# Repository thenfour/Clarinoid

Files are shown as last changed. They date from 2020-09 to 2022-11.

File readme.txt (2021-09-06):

Clarinoid.

VS Code + platformio for teensy
(GCC)
https://code.visualstudio.com/docs/cpp/config-mingw

....

Info about polyblep oscillators & hard sync:
http://www.martin-finke.de/blog/articles/audio-plugins-018-polyblep-oscillator/
ValimakiPeknenNam-jasa2012.pdf
https://www.cs.cmu.edu/~eli/papers/icmc01-hardsync.pdf

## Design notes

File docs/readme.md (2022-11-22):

# Clarinoid

## Links to other docs

* [Development notes, including how to reduce static memory bloat](development.md)
* [Modulation specification](modulation.md)
* [Notes about oscillator dev](oscillators.md)

## Projects

### Clarinoid2
This is for Clarinoid2, not the original prototype #1. I believe that was arduino only, and had separate LH and RH projects.

### Bassoonoid

### Test Device
I don't think this is actually used, but should be now that the test device is working.

### Bommanoid

## Control / input mapping

So i wrote this a while ago (2020) and forgot how it works, several times. Therefore lets document it a bit? I'll use Bassoonoid as an example.

The point is to go from hardware input to something that can be used deep in code. Buttons can perform functions. Pressure sensors and potentiometers will map float value to float value.

One of the reasons the design is more complex than you might think is because I want to support user-editable control mappings. So mappings are unified in a generic way, theoretically configurable at runtime. This is not possible yet but maybe in the future?

### Base system settings / enum PhysicalControl

```c++
    BaseSystemSettings.hpp / 
    enum class PhysicalControl : uint8_t
    {
        CPBack,
        CPOk,
        Breath,
        Pitch,
        ...
        COUNT,
    }

```

### Control mapper

```c++
    struct BommanoidControlMapper : IInputSource, ITask

    virtual void TaskRun() override
    {
        NoInterrupts _ni;
        mEncoder.Update();

    virtual void InputSource_Init(struct InputDelegator *p) override
    {
        mControlInfo[(size_t)PhysicalControl::Enc] = ControlInfo{"ENC", &mEncoder};
```
### IInputSource

```c++
    struct IInputSource
    {
        virtual void InputSource_Init(struct InputDelegator *) = 0;
        virtual size_t InputSource_GetControlCount() = 0;
        virtual ControlInfo InputSource_GetControl(PhysicalControl index) = 0;
        virtual void InputSource_ShowToast(
            const String &s) = 0; // this is a bit odd but allows the input delegator to show toasts to the GUI.
    };
```

### ControlInfo

### App init

Create default control mappings:

```c++
        mInputDelegator.Init(&mAppSettings, &mControlMapper);

        mAppSettings.mControlMappings[0] =
            ControlMapping::MomentaryMapping(PhysicalControl::LHOk, ControlMapping::Function::MenuOK);
        mAppSettings.mControlMappings[1] =
            ControlMapping::MomentaryMapping(PhysicalControl::LHBack, ControlMapping::Function::MenuBack);
```

### InputDelegator

The `InputDelegator` is a generic class which performs mapped actions. While controlmapper associates hardware controls with control info, input function mappings are in app settings. `InputDelegator` will bring all this together. It looks at control mappings in your settings, and applies the functions / param mappings.

Seems simple, but it means there are a set number of fixed "virtual controls" that real controls map to, or other control destinations. All those virtual controls derive from `FunctionHandler` and must implement `Update` and `GetCurrentValue`.

**Note** that this is not an `ITask`; it is not part of the TaskManager cycle. It's updated from `MusicalStateTask`. Why? Not sure really.

```c++
struct InputDelegator
{
    AppSettings *mpAppSettings = nullptr;
    IInputSource *mpSrc = nullptr; // <-- the app-specific control mapper

    VirtualSwitch mMenuOK;
    VirtualEncoder mMenuScrollA;
    VirtualAxis mBreath;
    SynthPresetAMappableFunction mSynthPresetAFn;
    ///...

    void Init(AppSettings *appSettings, IInputSource *psrc)
    {
        RegisterFunction(ControlMapping::Function::Nop,
                         &mMenuBack); // anything works; it's never called.

        RegisterFunction(ControlMapping::Function::MenuOK, &mMenuOK);
        RegisterFunction(ControlMapping::Function::MenuScrollA, &mMenuScrollA);
        RegisterFunction(ControlMapping::Function::Breath, &mBreath);
        RegisterFunction(ControlMapping::Function::SynthPresetA, &mSynthPresetAFn);
        ///...
    }

    void Update()
    {
        /// for each input mapping, finds the FunctionHandler for it, and calls fn->Update(mapping, controlmapper)
    }
};

```

### FunctionHandler

```c++
    virtual ControlValue FunctionHandler_GetCurrentValue() const = 0;
    virtual void FunctionHandler_Update(const ControlValue &) = 0;
```

## what happens when you press a button, turn an encoder, or apply breath pressure?

1. `BommanoidControlMapper::TaskRun()` updates the internal value of the control. The internal value is not unified; it's basically managed by the driver itself. So a simple: `mEncoder.Update();`.
1.

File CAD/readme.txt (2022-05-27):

for teensy footprints & symbols, go to 
https://github.com/XenGi/teensy_library
https://github.com/XenGi/teensy.pretty

why are there Symbols & Symbols2?
because KiCad changed formats so Symbols is old stuff
and Symbols2 is new.

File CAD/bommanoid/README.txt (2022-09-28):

korgmicrokey37.FCStd = nothing really
sketch1.FCStd = nothing really
ideal.FCStd = some bell placement ideas (obsolete mostly)
speakercab1.FCStd = proposed prod design of cab, with actual dimensions
bommanoid00 = sketches of keyboard case design; not for prod
bommanoid01 = fork of clarinoid test device 05; bringing in all bommanoid components.
              schematic, pcb sketches, and footprints added. not everything 100% double-checked.
              beginning to build pcbs out and do final checks, lets fork before i
              ruin my sketches.
bommanoid02 = continuing design & first attempts at routing
bommanoid03 = continuing routing; it's basically done before panelization & jlcpcb BOM
bommanoid04 = very close, including peripheral breakouts. but still bottom assembly issues.
bommanoid05 = RC1. fx loop, suspended castellated subboard for bottom assembly, part selection
              panelization and ERC / DRC are clean (well there are 99 expected errors due to silkscreen & castellated holes bugs)
              separating into separate orders for jlcpcb.

speakercab2.FCStd = some changes to design:
  - 10"
  - downfacing with no baffle (weight!)

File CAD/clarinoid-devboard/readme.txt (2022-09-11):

00 - 20220612 first work of a clarinoid3 test board. maybe biting off more than i can chew though.
01 - 20220612 let's break up that board into multiple sections
    20220618 after some work, this thing is pretty much the MEGA tester with tons of stuff.
              while that's nice work and nice thought, i think it's too risky for 1st try.
              let's simplify then come back to this.
02 - 20220618 - let's simplify back?
     eh, problem is i actually want to test all that stuff in 1 go. let's just make sub-boards.
03 - 20220618 copied from 01. let's just separate certain modules into sub-modules
04 - LED drivers are actually a nightmare and they're not really essential to this project. forget about them.
     need to separate:
     x dac (5)
     - midi
     - would be nice to have a way to switch between battery  or usb power

     20220620: 04 is being produced by jlcpcb

     THIS IS REV 1

05 - now using teensy 4.1 with pins. ready for assembly.
     and even more modular design

     this was rejected; added 05-asm and 05-noasm to separate assembly versus non-assembly boards in hopes
     of cost savings and build simplification.

06 - that still wasn't enough; need to break yet into <=6 designs per board.
     this is exactly the same design as 05, but broken into more separate projects.
     produced by jlcpcb.

     THIS IS REV 2

07 - the battery charge board of 05/06 was faulty somehow. i don't understand why and 2 fried.
     so here a variation with:
     - EH pad as it was on 04
     - inductor correct part #
     - 0.5mm traces
     - output capacitors
     - component sizes matching that of MH-CD42

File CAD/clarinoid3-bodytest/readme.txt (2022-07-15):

fork of devboard-04, combined with body design sketches from \CAD\clarinoid3-devboardfork\00
for proto & testing of physical:
- physical clearance
- ergonomics
- strength of body

- castellated holes
- volume placement & sub-board
- panelization of sub-boards
- inter-board headers
- front & back assembly
- various cap touch slider patterns

00 = initial; actually made a lot of progress already. LH pretty much done.
01 = let's work on RH and try to get this thing produced.
     HM making a lot of progress, main subboard for example.
     but if i want ideal ergonomics / interconnect / component placement,
     then i am really running into space problems. i CAN fit everything,
     but placement is going to be compromised.
     i have this idea now to put the DAC and possible more on a sub-board,
     this will put it together as it's more critical for spacing / grounding,
     and it will ensure everything is close to the audio out jack. let's go to 02.
02 = trying adding more to pot subboard
03 = subboards & routings are done. but i'm not satisfied with the interconnect headers;
     i don't like that these are directly exposed on the outside wall;
     let's try SMT pin header footprints.
     i had also considered more sub-boards, maybe again mounted @ 90 degrees like
     the potentiometer. but mechanical stress & complexity concern me.
     in the spirit of experimenting/testing, let's go for SMD pin headers.

04 = micromod is not ideal for our design. benefit does not outweigh the cost regarding
     vibration, complexity, stability, convention.

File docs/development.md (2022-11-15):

# Random development notes

## Crash handling

Teensy's relatively new crash handling mechanism will output the address of failure. To use it,

1. make sure you build with `-g` to output symbols
```
build_flags =
  -I../../src
  -std=c++17
  -Wall
  -g
```

2. with the address, run:

```
"C:\Users\carl\.platformio\packages\toolchain-gccarmnoneeabi\bin\arm-none-eabi-addr2line.exe" -e "C:\root\git\thenfour\Clarinoid\projects\BOMMANOID\.pio\build\teensy41\firmware.elf" 0x117bc
```

## Bloaty & memory use
Teensy will crash mysteriously when running out of memory. Before 1.54, it was pretty hard to get quick insight about mem usage. But now we can see memory.

RAM1 is getting stretched thin much of the time, leaving a couple dozen kb for stack.

Statically-allocated things like lookup tables go there. So Modcurve LUT, scale follower, static variables.

Also CODE gets copied to RAM1 for speed, and this is actually significant, probably because of the amount of templated code we use.

For this it's very useful to use "bloaty". It runs on *nix (ubuntu in my case).

```
git clone https://github.com/google/bloaty.git
npm install cmake
cd bloaty
git submodule update --init --recursive
make -j6
./bloaty bloaty
```

## C++17

  * https://forum.pjrc.com/threads/58695-c-17
  * https://forum.pjrc.com/threads/60944-C-STL-on-the-Teensy-4-0-not-possible

Unfortunately, even with `-std=c++17`, we only get C++14 support. This is dictated by the platform toolchain, `- toolchain-gccarmnoneeabi @ 1.50401.190816 (5.4.1)`.

It's possible to specify a newer framework in the `platformio.ini`; search for `gccarmnoneeabi` on the registry. https://registry.platformio.org/tools/platformio/toolchain-gccarmnoneeabi

But if you do that, you'll get build & link errors, unable to use many features we require.

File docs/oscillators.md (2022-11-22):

# Oscillator development

## Ring Mod

Ring mod is a fairly "weak" type of modulation, and I have never really found great uses for it. But it's simple to implement.

## Hard Sync

## Band-limiting

## FM

FM is simple to implement, but there are quirks going on to make it behave in a musical way.

### Chained modulation

Phase restart is essential when using FM, otherwise the character would be inconsistent. There would be issues when portamento varies between oscillators too, so it may be that these need to be synchronized between oscillators in the future.

### Feedback

FM Feedback is known for being unstable, but at least it's usable. I found with the naive implementation, it starts to break up in glitchy ways at higher values. Digital-sounding glitches and octave shifting beeps, while the identical algorithm in JSFX or C++ produce expected "stable" waveforms.

See https://github.com/thenfour/Clarinoid/issues/193

Reducing all the way down to a few float ops per sample, and dumping the numeric results of identical code, it's confirmed that it's the result of FM feedback, amplifying and accumulating floating point discrepencies.

* See: `exprcmd.cpp`
* See: `\notes\osc accuracy analysis x86 comparison.xlsx`

For example, modulation between FM oscillators is not a problem. The error doesn't accumulate.

Note: `double` does not seem to affect anything; same glitching occurs.

I could dive deeper but I doubt it would get me closer to a solution. It may be in the implementation of `arm_sin_f32` (although I checked a taylor series version and had the same issues). But I suspect it's in very small differences in multiplication. Multiplying phase by `2*pi` seemed to be a source of error.

I have not found a solution for this, but some mitigations to mind.

* "recording" certain values to capture a single wave cycle. This would eliminate the accumulating errors, and ensure wave cycles sound stable / consistent. Unfortunately there are issues with regards to wave cycles not being exact sample lengths (which would cause detuning at high frequencies). Maybe mitigations can be done, like just calculating 1 fixed long waveform, and interpolating out of it, like a sample player. I'm not sure that would work either though because the feedback sound will depend on the ratio of frequency to samplerate.
* Resetting feedback state every wave cycle. I tried this, setting to either 1 (the value of `sin()` at the start of a cycle) or 0 (the initial state i used in JSFX to get good results); both seem to possibly help, but introduce other glitches and i'm not sure it's actually helping. Prefer simpler solution. Also we're going to suffer the same as above: cycle crossing won't be at even bounds.
* Use fixed-point math. Oscillators don't really benefit from floating-point style behaviors so maybe using fixed 32-bit math would help stabilize things.

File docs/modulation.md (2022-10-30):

# Modulations on Clarinoid

Trying to capture justifications for things here.

Modelled after the modulations I've used in the past. Some systems are not really translatable, like Renoise's meta devices or highly UI-dependent or grid-like types like FM8. But we have enough CPU to probably support whatever we need as long as it's focused and optimized.

The modulation systems that seem to make most sense to inspire from are Massive and Serum. And anyway modulations are not some kind of magic; the system sorta implies the design already. Recent work on 7jam also is largely the basis for this.

Note that modulations are critical for Clarinoid, for a few reasons:

* Mostly monophonic, therefore expression is more important. Modulations are where the richness and expression is.
* Everything revolves around breath, which is a modulation. It better be flexible in order to make diverse sounds.
* Because the filter is sorta blanketing everything, another reason we need other means to spice up the sound and keep it from all sounding the same.

## Algorithm

The fundamental algorithm to start with is

    output = base + modulation

Where `base` is a base value or signal (an oscillator frequency, or amplitude, or LFO rate). `Modulation` is a value or signal to add into the signal.

In practice, all signals are bipolar `[-1,1)`. Even modulation sources like Breath, which doesn't have any concept of negative values, is a signed signal with an unused negative pole.

### Ranges
Of course every parameter can have a different range. Breath is from `[0,1]` while filter cutoff frequency is `0-22000 hz`. These are all compressed into the `[-1,1)` signal range.

The function above is not that useful because there's no correspondance of scaling. Modulating frequency by LFO would heavily clip values and always scale the entire frequency range.

So accounting for scaling modulations to a certain range,

    output = base + modulation * scale

Now the user adjusts a scaling knob and the modulation is pretty useful just like this.

### Polarity

There are limitations with a simple `scale` parameter, and a simple `polarity` parameter can go a very long way for flexibility and workflow.

Scenario #1: You want `breath` to modulate `filter freq`, but you want the "resting" position to be at the extent rather than the base value. In other words, with simple scale as above, you get a transfer that looks like:

             0==> +         breath
    <--------|-------->     incoming signal
             ^base

But here's what you want:

           + <==0           breath
    <--------|-------->     incoming signal
             ^base

That's common. In Massive when I want to make this type of mapping, it requires constantly tweaking two parameters at the same time: Base value, and modulation scale. This scenario would do it ith 1 knob.

Scenario #2: You want `LFO` to modulate only in the positive pole. LFO is natively bipolar, but you can specify that you want it to be adjusted to be positive.

        - <==0==> +         LFO
    <--------|-------->     incoming signal
             ^base

But we'd like to be able to map it into positive pole:

           - <==0==> +    LFO
    <--------|-------->     incoming signal
             ^base

While we're at it, we can also invert the signal.

           + <==0==> -    LFO
    <--------|-------->     incoming signal
             ^base

Or inverting bipolar,

        + <==0==> -    LFO
    <--------|-------->     incoming signal
             ^base

Fortunately all these scenarios are possible with a single parameter which specifies a polarity mapping. And it's very efficient, every possible mapping reduced to a single multiple & add.

    ConvertPolarity(..) {
        if (naturalPolarity == POS && mSourcePolarity == N11){
          x = x*2-1
        } else (if naturalPolarity == BIPOLARN11 && mSourcePolarity == POS) {
          x = x*.5+.5
        } else if (naturalPolarity == POS && mSourcePolarity == positiveInv){
          x = 1-x
        } else (if naturalPolarity == BIPOLARN11 && mSourcePolarity == positiveInv) {
          x = .5-x*.5
        } else if (naturalPolarity == POS && mSourcePolarity == bipolarInv){
          x = .5-x*2
        } else (if naturalPolarity == BIPOLARN11 && mSourcePolarity == bipolarInv) {
          x = -x
        }
    }

## Curves

Effort was put into creating curves which are useful, accurate, flexible, and optimized.

For performance reasons a LUT is used and linear interpolation is used. X axis is sample value, and Y axis is `k`, representing a curve amount, `[-1,1]`. Since the Y axis is not interpolated, we just use integral indices. It's also more efficient to handle the `0` case where there's no mapping performed.

We cannot use a simple `pow` curve because it's sorta biased over towards one side, and because this is general purpose it should not bias one direction or another.

A circular curve is used then, which can transform from linear all the way to pushed up in the corner.

The original formula is:

    (1-x)^k + y^k = 1

solved for y, that's

    y = (1-x^k)^(1/p)

Then some `1-x` style transforms to mirror it around negative `k` and `x` values.

## Auxiliary signals

Serum has a system of "auxilliary" modulation sources, which allows basically modulating modulations. I do find it useful to think of it this way, instead of having to create a new modulation to modulate this one. So, better workflow, more optimal code, and it replaces certain kinds of hidden details like envelope velocity tracking.

Serum works in this way:

    y = x + (modSrcVal * scale * auxVal * auxScale)

I don't really like this though; I don't find it that useful. An aux source to me is an attenuation of the main modulation. It's not just another multiplication.

The example which illustrates this is: Envelope -> Volume, with velocity aux. This is probably the most common type of modulation imagineable. In this scenario, the mod scale sets the envelope peak, and aux amount would be the amount of attenuation caused by velocity.

The Serum way means this is not a very useful interaction. With a "small amount of velocity-based attenuation", i.e. a small aux scale, multiplying like above causes the env peak to be very quiet.

What we really want is that the aux value does a `lerp` between an `(attenuated modscale)` and `modscale`.

    scale = lerp(modScale - auxScale, modScale, auxVal)
    y = x + (modSrcVal * scale)

Now e.g. when `modScale=0.5`, `velocity=0.1`, and `auxScale=0.333`,

    scale = lerp(0.5 - 0.333, 0.5, 0.1)
    y = x + (modSrcVal * scale)

There's a pretty optimal way of doing this, by precalculating an `auxBase` (the left edge of the `lerp`).

    auxBase = 1 - auxScale // precalculated
    auxMul = auxBase + auxVal * auxScale

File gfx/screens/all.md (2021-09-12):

# Performance Page 1/3

01PerformanceOverview

1. Synth Patch A selection
    1. double click: mute / unmute
1. Synth Patch B selection
    1. double click: mute / unmute
1. Harmonizer patch selection
    1. double click: mute / unmute
1. Master gain
1. Stereo spread / narrow
1. FX Gain
    1. double click: mute / unmute
1. BPM
    1. double click: Metronome mute / unmute
1. Transpose semitones
1. Scale root
1. Scale flavor

# Performance Page 2/3: Reverb FX
02Verb

1. Verb size
1. Verb damp
1. Verb gain
    1. double click: verb mute / unmute

# Performance Page 3/3: Delay FX
03Delay

1. Delay gain
    1. double click: verb mute / unmute
1. Delay time
1. Delay time basis (ms, various note lengths)
1. Delay time stereo spread
1. Feedback gain
1. Feedback filter type
1. Feedback cutoff
1. Feedback saturation
1. Feedback resonance (Q)

# Synth Patch Page 1/x: Overview
00PatchOverview

1. Patch gain
1. Stereo spread
1. Detune
1. Patch verb MIX
1. Patch delay SEND
1. Macro 1 amount (0-1)
1. Macro 2 amount (0-1)
1. Macro 3 amount (0-1)
1. Macro 4 amount (0-1)

# Synth Patch Page 2/x: OSC settings page 1
01PatchOSC1

1. Osc1 frequency semis
1. Osc1 frequency finetune
1. Osc1 waveform select (square, etc)
1. Osc1 wave shape parameter 1. for PWM, this is pulse width. for vartri or other wave-wave types, blend. anything which morphs the wave.
1. Osc1 wave shape parameter 2. for PWM, not used. for vartri, curve. for sine, PM feedback amount.
1. Osc1 Phase
    1. double click: phase restart / phase continuous
1. Hard sync base frequency.
    1. double-click: enable / disable hard sync

(repeat for Osc2 and Osc3)

# Synth Patch Page 3/x: OSC settings page 2
02PatchOSC2

1. Osc1 Amp
    1. double click: mute / unmute
1. Osc1 Pan
1. Osc1 Portamento time
1. Osc1 Pitchbend range POSITIVE
1. Osc1 Pitchbend range NEGATIVE
1. Osc1 Pitchbend semitone snap period

(repeat for Osc2 and Osc3)

# Synth Patch Page 4/x: FM

03PatchFM

1. FM strength Osc2 => Osc1
1. FM strength Osc3 => Osc1
1. FM strength Osc1 => Osc2
1. FM strength Osc3 => Osc2
1. FM strength Osc1 => Osc3
1. FM strength Osc2 => Osc3
1. FM feedback strength Osc1
1. FM feedback strength Osc2
1. FM feedback strength Osc3
1. Osc1 output gain
1. Osc2 output gain
1. Osc3 output gain
1. Osc1 Frequency multiplier
1. Osc2 Frequency multiplier
1. Osc3 Frequency multiplier
1. Osc1 Frequency offset
1. Osc2 Frequency offset
1. Osc3 Frequency offset
1. Overall FM strength

# Synth Patch Page 5/x: Filter
04PatchFilter

1. Filter type
1. Filter stereo separator
1. Filter cutoff Hz
1. Filter saturation
1. Filter resonance (Q)

# Synth Patch Page 6/x: Modulation Overview
05ModulationsOverview

1. LFO1 submenu
1. LFO2 submenu
1. Env1 submenu
1. Env2 submenu
1. Custom modulation 1 submenu
1. Custom modulation 2 submenu
1. Custom modulation 3 submenu
1. Custom modulation 4 submenu
1. Custom modulation 5 submenu
1. Custom modulation 6 submenu
1. Custom modulation 7 submenu
1. Custom modulation 8 submenu

# Synth Patch Page 7/x: Tools

09PatchTools

1. Patch pan
1. Voicing mode: mono / poly
1. Init patch (with confirmation)
1. Copy patch (show list of destination, then confirmation)
1. Init osc1
1. Init osc2
1. Init osc3
1. Copy osc1 to... (show list of destination, then confirmation)

# Synth Patch: Modulation detail

06ModulationDetail

1. Modulation source signal
1. Modulation destination param
1. Modulation source curve strength
1. Modulation source polarity
1. Modulation destination param base value
1. Modulation scale
1. Modulation aux source signal
1. Modulation aux curve
1. Modulation aux polarity
1. Modulation aux scale
    1. double click: aux disable / enable

# Synth Patch: Modulation envelope

07ModEnvelope

1. Env delay time
1. Env attack time
1. Env hold time
1. Env decay time
1. Env sustain level
1. Env release time
1. Env transitional release time

# Synth Patch: Modulation LFO

08ModLFO

1. LFO Wave type
1. LFO Wave shape param
1. LFO pulse width
1. LFO frequency
1. LFO frequency basis (ms, various notes)
1. LFO phase offset
    1. double click: LFO phase restart / continuous

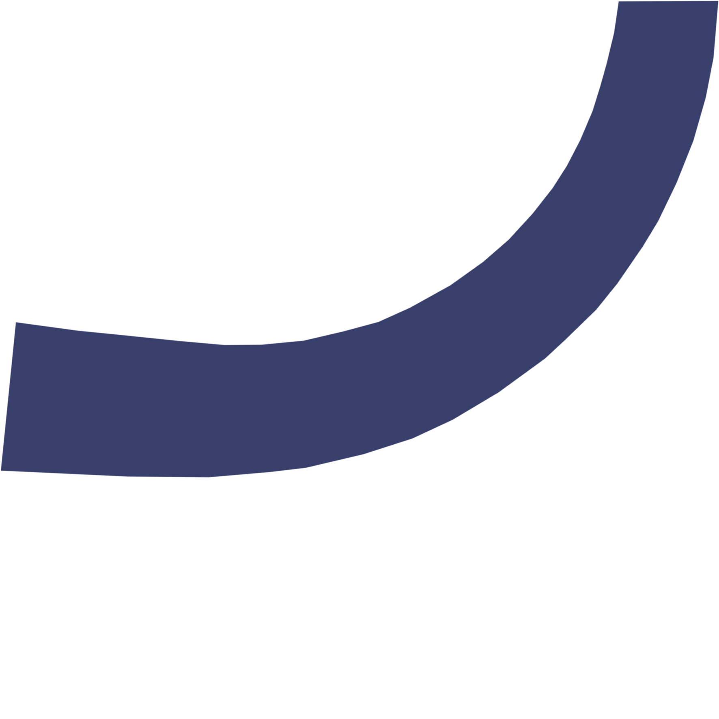
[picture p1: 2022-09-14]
CAD/bommanoid/bellext1.png

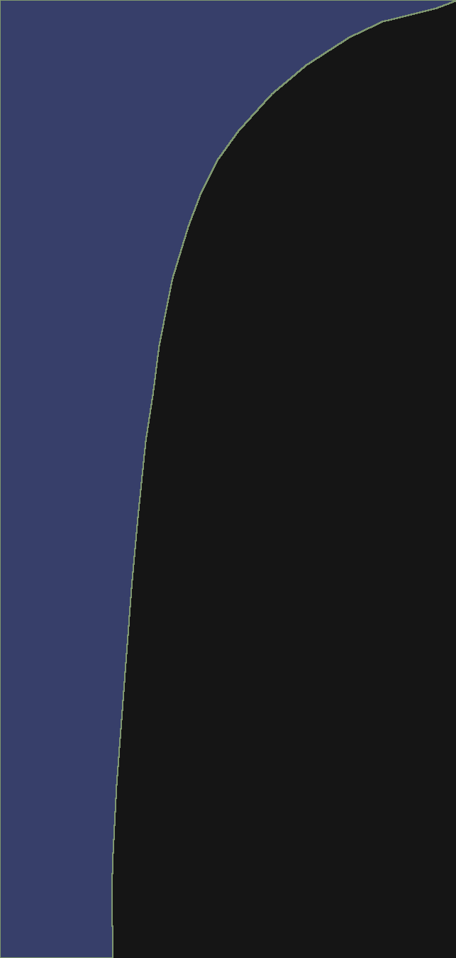
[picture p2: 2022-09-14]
CAD/bommanoid/bellprofile2.png

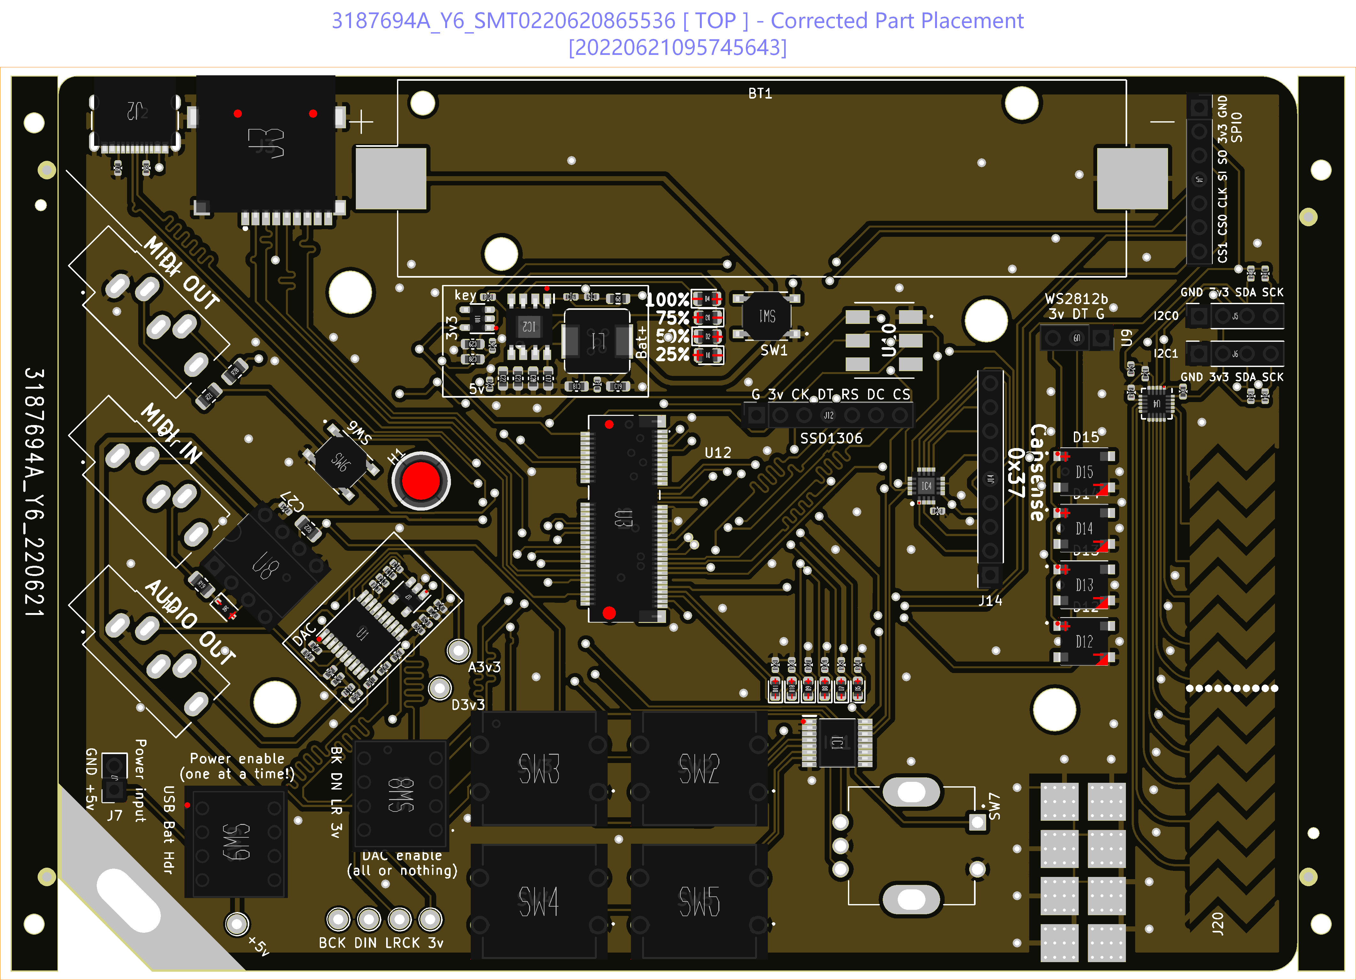
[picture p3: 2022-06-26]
CAD/clarinoid-devboard/clarinoid-devboard-04/jlcpcb/Produce_DanZhi.SMT_Snapshot.Top.3187694A_Y6.SMT0220620865536.png

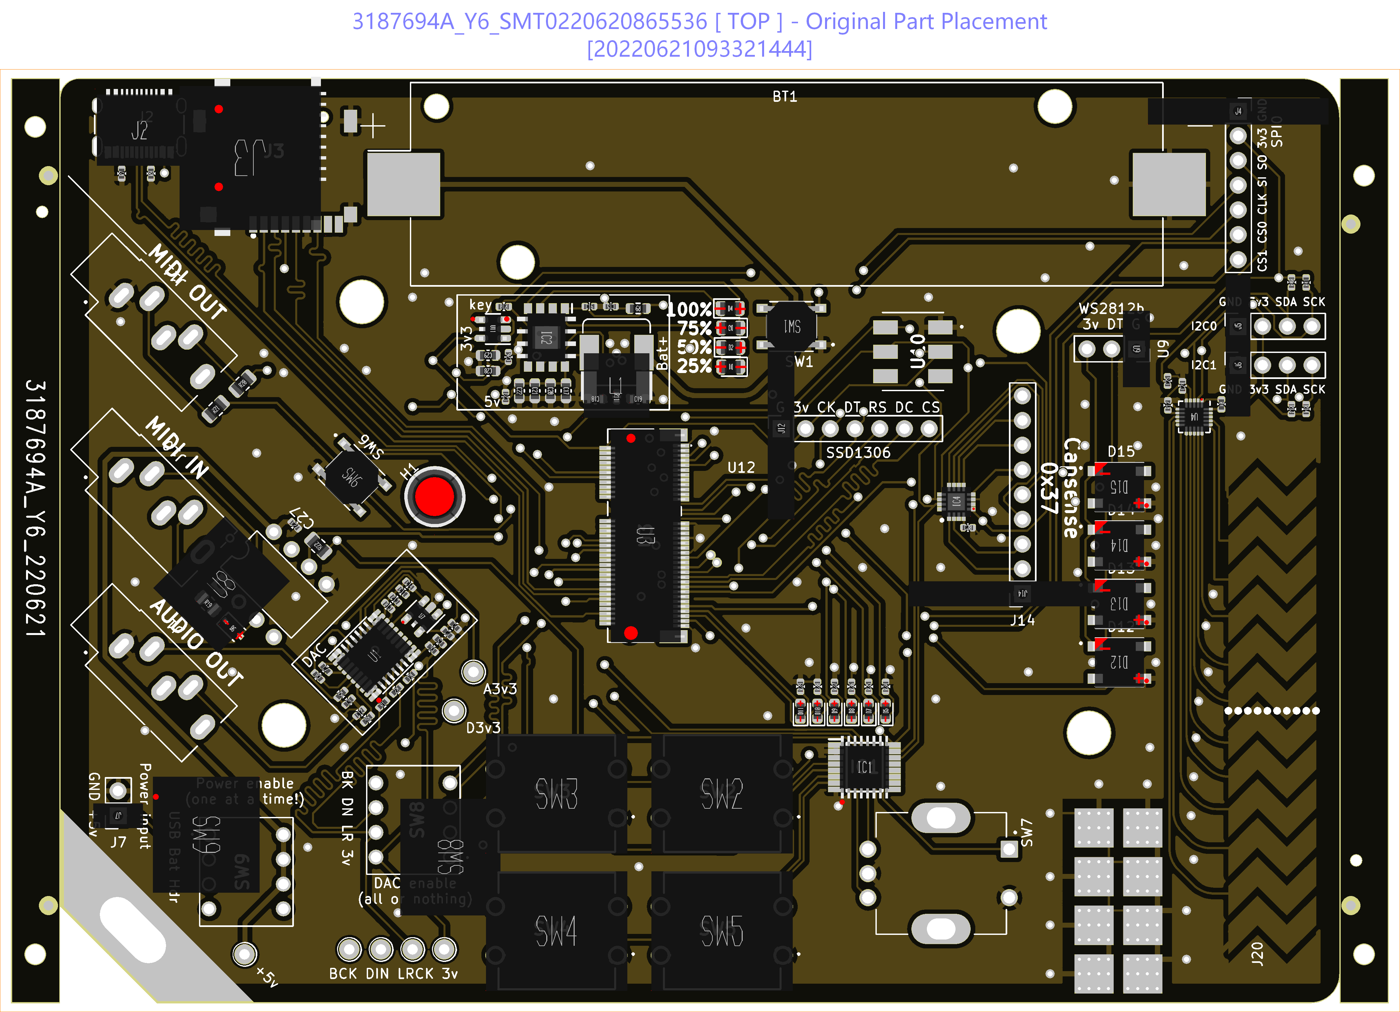
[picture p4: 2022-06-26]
CAD/clarinoid-devboard/clarinoid-devboard-04/jlcpcb/Produce_DanZhi.SMT_Original_Snapshot.Top.3187694A_Y6.SMT0220620865536.png

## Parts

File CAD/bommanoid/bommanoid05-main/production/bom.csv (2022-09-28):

Designator | Footprint | Quantity | Value | LCSC Part #
C1, C11, C13, C6, C7 | C_0805_2012Metric | 5 | 10uF | C15850
C10, C12, C15, C19, C2, C25, C9 | C_0805_2012Metric | 7 | 0.1uF | C49678
C14, C18 | C_0805_2012Metric | 2 | 0.22uF | C5378
C16, C26 | C_1206_3216Metric | 2 | 10uF | C13585
C17 | C_0805_2012Metric | 1 | 1uF | C28323
C20, C33 | C_1206_3216Metric | 2 | 0.1uF | C24497
C21, C22, C23, C24, C27, C28, C29, C30, C31, C32 | C_1206_3216Metric | 10 | 22uF | C12891
C3, C4, C5, C8 | C_0805_2012Metric | 4 | 2.2uF | C49217
D1 | D_MiniMELF | 1 | 3.3v | C393436
D16, D17, D18, D19, D20 | LED_0805_2012Metric | 5 | red | C264424
D2 | D_SOD-323 | 1 | 1N4148WS | C2128
H1 | Sinhoo SMTSO2530CTJ | 1 | M.2 riser 2.5mm | C2915630
IC3 | SOIC127P599X155-9N (IP5306) | 1 | Injoinic IP5306 battery charge | C181692
J10, J19 | PinSocket_1x07_P2.54mm_Vertical | 2 | Conn_01x07 | C358721
J13 | PinSocket_1x09_P2.54mm_Vertical | 1 | Conn_01x09 | C39576
J15, J16 | PinSocket_1x12_P2.54mm_Vertical | 2 | Conn_01x12 | C350303
J18 | PinSocket_1x03_P2.54mm_Vertical | 1 | Conn_01x03 | C146243
J23, J24, J60 | PinSocket_1x05_P2.54mm_Vertical | 3 | Conn_01x05 | C50950
J61 | RJ45_Amphenol_RJHSE538X | 1 | RJ45_LED_Shielded | C464587
J62 | PinSocket_1x08_P2.54mm_Vertical | 1 | Conn_01x08 | C27438
L1 | Inductor_MCS0630-1R0MN2 | 1 | 1uH-psa | C385251
R1, R2, R3 | R_1206_3216Metric | 3 | 22R | C17958
R10 | R_1206_3216Metric | 1 | 220R | C17957
R11, R4, R5 | R_1206_3216Metric | 3 | 470R | C4502
R12, R13 | R_1206_3216Metric | 2 | 47R | C17969
R27 | R_1206_3216Metric | 1 | 2R | C17942
R28 | R_1206_3216Metric | 1 | 10k | C17902
R29 | R_1206_3216Metric | 1 | 0.5R | C25340
R47, R48, R49, R50, R51, R52, R53, R54, R57, R58, R59, R60, R61, R62, R63 | R_0805_2012Metric | 15 | 220 | C17557
R6, R7 | R_1206_3216Metric | 2 | 4.7k | C17936
R8 | R_1206_3216Metric | 1 | 100k | C17900
U1 | TSSOP-20_4.4x6.5mm_P0.65mm | 1 | PCM5102A | C107671
U2, U3 | SOT-23-5 | 2 | TLV75733PDBV | C485517
U4 | APCI0108-P001A M.2 MicroMod 21992304 | 1 | APCI0108-P001A Teensy_4.0_MicroMod | C841659
U5 | TSSOP-16_4.4x5mm_P0.65mm | 1 | TCA9554PW | C86803
U7 | DIP-8_W7.62mm | 1 | 6N138 | C571211

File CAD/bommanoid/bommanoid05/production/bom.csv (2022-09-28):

Designator | Footprint | Quantity | Value | LCSC Part #
C1, C11, C13, C6, C7 | C_0805_2012Metric | 5 | 10uF | C15850
C10, C12, C15, C19, C2, C25, C9 | C_0805_2012Metric | 7 | 0.1uF | C49678
C14, C18 | C_0805_2012Metric | 2 | 0.22uF | C5378
C16, C26 | C_1206_3216Metric | 2 | 10uF | C13585
C17 | C_0805_2012Metric | 1 | 1uF | C28323
C20, C33, C35 | C_1206_3216Metric | 3 | 0.1uF | C49678
C21, C22, C23, C24, C27, C28, C29, C30, C31, C32 | C_1206_3216Metric | 10 | 22uF
C3, C4, C5, C8 | C_0805_2012Metric | 4 | 2.2uF | C49217
C34 | C_1206_3216Metric | 1 | 0.33uF
D1 | D_MiniMELF | 1 | 3.3v | C393436
D16 | LED_0805_2012Metric | 1 | korgpwr | C264424
D17 | LED_0805_2012Metric | 1 | 25% | C264424
D18 | LED_0805_2012Metric | 1 | 50% | C264424
D19 | LED_0805_2012Metric | 1 | 75% | C264424
D2 | D_SOD-323 | 1 | 1N4148WS | C2128
D20 | LED_0805_2012Metric | 1 | 100% | C264424
D27, D28, D31, D33, D35, D36, D37, D38 | LED_WS2812B-B Worldsemi | 8 | WS2812B
H1 | Sinhoo SMTSO2530CTJ | 1 | M.2 riser 2.5mm | C2915630
H23 | MountingHole_5.3mm_M5 | 1 | MountingHole_fb
IC3 | SOIC127P599X155-9N (IP5306) | 1 | Injoinic IP5306 battery charge | C181692
J10, J19 | PinSocket_1x07_P2.54mm_Vertical | 2 | Conn_01x07
J13 | PinSocket_1x09_P2.54mm_Vertical | 1 | Conn_01x09
J15, J16 | PinSocket_1x12_P2.54mm_Vertical | 2 | Conn_01x12
J18, J71 | PinSocket_1x03_P2.54mm_Vertical | 2 | Conn_01x03
J23, J24, J60, J78 | PinSocket_1x05_P2.54mm_Vertical | 4 | Conn_01x05
J26, J54 | JST_PH_B2B-PH-K_1x02_P2.00mm_Vertical | 2 | Conn_01x02
J29, J30, J31, J61, J84 | RJ45_Amphenol_RJHSE538X | 5 | RJ45_LED_Shielded
J34, J53, J55, J58 | JST_PH_B4B-PH-K_1x04_P2.00mm_Vertical | 4 | Conn_01x04
J62, J82 | PinSocket_1x08_P2.54mm_Vertical | 2 | Conn_01x08
J69 | PinSocket_1x02_P2.54mm_Vertical | 1 | Conn_01x02
J73 | PinSocket_1x04_P2.54mm_Vertical | 1 | Conn_01x04
J80 | PinSocket_1x06_P2.54mm_Vertical | 1 | Conn_01x06
J86 | USB_C_Receptacle_XKB_U262-16XN-4BVC11 | 1 | XKB_U262-16XN-4BVC11 USB-C recept | C319148
L1 | Inductor_MCS0630-1R0MN2 | 1 | 1uH-psa | C385251
NT5 | NetTie-2_SMD_Pad1.0mm | 1 | NetTie_2
R1, R2, R3 | R_1206_3216Metric | 3 | 22R | C17958
R10 | R_1206_3216Metric | 1 | 220R | C17957
R11, R4, R5 | R_1206_3216Metric | 3 | 470R | C4502
R12, R13 | R_1206_3216Metric | 2 | 47R | C17969
R26, R46 | R_1206_3216Metric | 2 | 5.1k | C26033
R27 | R_1206_3216Metric | 1 | 2R
R28 | R_1206_3216Metric | 1 | 10k
R29 | R_1206_3216Metric | 1 | 0.5R
R47, R48, R49, R50, R51, R52, R53, R54, R57, R58, R59, R60, R61, R62, R63 | R_0805_2012Metric | 15 | 220
R6, R7 | R_1206_3216Metric | 2 | 4.7k | C17936
R8 | R_1206_3216Metric | 1 | 100k | C17900
U1 | TSSOP-20_4.4x6.5mm_P0.65mm | 1 | PCM5102A | C107671
U2, U3 | SOT-23-5 | 2 | TLV75733PDBV | C485517
U4 | APCI0108-P001A M.2 MicroMod 21992304 | 1 | APCI0108-P001A Teensy_4.0_MicroMod | C841659
U5 | TSSOP-16_4.4x5mm_P0.65mm | 1 | TCA9554PW
U7 | DIP-8_W7.62mm | 1 | 6N138 | C571211

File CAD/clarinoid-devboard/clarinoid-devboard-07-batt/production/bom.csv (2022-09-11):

Designator | Footprint | Quantity | Value | LCSC Part #
C1, C10, C11, C12, C13, C18, C19, C2, C3, C4, C8, C9 | C_0805_2012Metric | 12 | 22uF | C602037
C14, C5 | C_0805_2012Metric | 2 | 0.1uF | C49678
C15, C16, C6, C7 | C_0805_2012Metric | 4 | 10uF | C15850
C17, C20, C28, C29 | C_1206_3216Metric | 4 | 10uF | C13585
C21, C22, C23, C24, C30, C31, C32, C33 | C_1206_3216Metric | 8 | 22uF | C12891
C25, C26, C34, C35 | C_0603_1608Metric | 4 | 22uF | C59461
C27, C36 | C_1206_3216Metric | 2 | 0.1uF | C24497
D1, D13, D5, D9 | LED_0805_2012Metric | 4 | 25% | C264424
D10, D14, D2, D6 | LED_0805_2012Metric | 4 | 50% | C264424
D11, D15, D3, D7 | LED_0805_2012Metric | 4 | 75% | C264424
D12, D16, D4, D8 | LED_0805_2012Metric | 4 | 100% | C264424
H1, H2, H3, H6 | MountingHole_3.2mm_M3 | 4 | MountingHole
IC1, IC2, IC3, IC4 | SOIC127P599X155-9N (IP5306) | 4 | Injoinic IP5306 battery charge | C181692
L1, L3 | Inductor_MCS0630-1R0MN2 | 2 | 1uH-Sunlord | C112125
L2, L4 | Inductor_MCS0630-1R0MN2 | 2 | 1uH-psa | C385251
R1, R9 | R_1206_3216Metric | 2 | 2R | C17942
R10, R2 | R_1206_3216Metric | 2 | 10k | C17902
R11, R3 | R_1206_3216Metric | 2 | 0.5R | C25340
R12, R6 | R_0603_1608Metric | 2 | 0.5R | C45312
R4, R7 | R_0603_1608Metric | 2 | 2R | C22977
R5, R8 | R_0603_1608Metric | 2 | 10k | C25804
SW1, SW2, SW3, SW4 | XKB switch jlcpcb SW_TS-1187A-B-A-B | 4 | SW_Push | C318884

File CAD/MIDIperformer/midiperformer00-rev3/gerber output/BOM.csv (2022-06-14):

Comment | Designator | Footprint | LCSC
0.1uF | C1,C2 | Capacitor_SMD:C_0402_1005Metric | C1525
1N4148 | D1,D2 | Diode_SMD:D_SOD-123 | C81598
MountingHole | H1,H2 | MountingHole:MountingHole_3.2mm_M3_Pad
MIDI IN B | J1 | Connector_PinSocket_2.54mm:PinSocket_1x03_P2.54mm_Vertical
MIDI IN A | J2 | Connector_PinSocket_2.54mm:PinSocket_1x03_P2.54mm_Vertical
MIDI OUT A | J3 | Connector_PinSocket_2.54mm:PinSocket_1x03_P2.54mm_Vertical
MIDI OUT B | J4 | Connector_PinSocket_2.54mm:PinSocket_1x03_P2.54mm_Vertical
Barrel_Jack | J5 | Connector_PinSocket_2.54mm:PinSocket_1x02_P2.54mm_Vertical
Conn_02x08_Counter_Clockwise | J6 | Connector_PinSocket_2.54mm:PinSocket_2x08_P2.54mm_Vertical
220 | R1,R2 | Resistor_SMD:R_0402_1005Metric | C25091
47 | R3,R4,R5,R6 | Resistor_SMD:R_0402_1005Metric | C25118
470 | R7,R8 | Resistor_SMD:R_0402_1005Metric | C25117
330 | R9,R10,R11,R12,R13,R14,R15,R16 | Resistor_SMD:R_0402_1005Metric | C25104
SW_Push | SW1 | Connector_PinSocket_2.54mm:PinSocket_1x02_P2.54mm_Vertical
6N138 | U1,U2 | Package_DIP:DIP-8_W7.62mm | C255743
L7805 | U3 | Package_TO_SOT_SMD:TO-252-2 | C54285
Teensy-LC | U4 | clarinoid2:Teensy_LC
WS2812 | U5 | Connector_PinSocket_2.54mm:PinSocket_1x03_P2.54mm_Vertical

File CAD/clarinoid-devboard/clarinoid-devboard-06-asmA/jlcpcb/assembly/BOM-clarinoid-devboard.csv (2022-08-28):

Comment | Designator | Footprint | LCSC
PCM5102A | U1 | TSSOP-20_4.4x6.5mm_P0.65mm | C107671
WS2812 | U38 | PinSocket_1x03_P2.54mm_Vertical | C146243
10uF | C10,C11,C3,C5 | C_0805_2012Metric | C15850
4.7k | R40,R41 | R_1206_3216Metric | C17936
220R | R19 | R_1206_3216Metric | C17957
22R | R1,R2,R3 | R_1206_3216Metric | C17958
47R | R20,R21 | R_1206_3216Metric | C17969
1N4148WS | D6 | D_SOD-323 | C2128
5.1k | R7,R8 | R_1206_3216Metric | C26033
4p | J31,J5,J8 | PinSocket_1x04_P2.54mm_Vertical | C2718488
Conn_01x08 | J44 | PinSocket_1x08_P2.54mm_Vertical | C27438
XKB_U262-16XN-4BVC11 USB-C recept | J2 | USB_C_Receptacle_XKB_U262-16XN-4BVC11 | C319148
female 1x6 | J45,J52,J53,J6 | PinSocket_1x06_P2.54mm_Vertical | C358720
SSD1306 | J12 | PinSocket_1x07_P2.54mm_Vertical | C358721
470R | R22,R34,R35,R36,R37,R5,R6 | R_1206_3216Metric | C4502
TLV75733PDBV | U7 | SOT-23-5 | C485517
2.2uF | C12,C7,C8,C9 | C_0805_2012Metric | C49217
header_power tap | J32,J33 | PinSocket_1x02_P2.54mm_Vertical | C49661
0.1uF | C13,C14,C23,C27,C4,C6 | C_0805_2012Metric | C49678
Conn_01x20 | J43 | PinSocket_1x20_P2.54mm_Vertical | C50984
6N138 | U8 | DIP-8_W7.62mm | C571211
22uF | C17,C20,C21,C22 | C_0805_2012Metric | C602037
blue | D5,D7 | LED_0603_1608Metric | C72041
green | D8,D9 | LED_0603_1608Metric | C72043
SW_Push | SW2,SW3,SW4,SW5 | B3F-4055 | C84931
PCA9554APW,118 | IC1 | SOP65P640X110-16N | C86803
MountingHole | H15 | MountingHole_3.2mm_M3
MountingHole | H7 | MountingHole_3.2mm_M3
MountingHole | H14 | MountingHole_3.2mm_M3
MountingHole | H8 | MountingHole_3.2mm_M3
MountingHole | H13 | MountingHole_3.2mm_M3

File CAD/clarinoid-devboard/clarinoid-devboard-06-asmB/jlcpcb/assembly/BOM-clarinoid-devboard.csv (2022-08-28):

Comment | Designator | Footprint | LCSC
microSD SOFNG TF-15x15 | J38 | SOFNG TF-15x15 (LCSC C111196) | C111196
1uH | L1 | Inductor_MCS0630-1R0MN2 | C112125
10uF | C1,C15,C16 | C_0805_2012Metric | C15850
100k | R14,R15 | R_1206_3216Metric | C17900
10k | R10,R4 | R_1206_3216Metric | C17902
2R | R9 | R_1206_3216Metric | C17942
75k | R12 | R_1206_3216Metric | C17986
Injoinic IP5306 battery charge | IC2 | SOIC127P599X155-9N | C181692
0.5R | R11 | R_1206_3216Metric | C25340
25% | D1,D2,D3,D4 | LED_0805_2012Metric | C264424
1uF | C29 | C_0805_2012Metric | C28323
M.2 riser 2.5mm | H4 | Sinhoo SMTSO2530CTJ | C2915630
SW_Push | SW1,SW6 | XKB switch jlcpcb SW_TS-1187A-B-A-B | C318884
3.3v | D12 | D_MiniMELF | C393436
CY8CMBR3108-LQXIT | IC3 | QFN50P300X300X60-17N-D | C462528
TLV75733PDBV | U19 | SOT-23-5 | C485517
0.1uF | C24,C25,C26,C28,C31,C32 | C_0805_2012Metric | C49678
Teensy4.1_RIGHT | U2,U3 | PinSocket_1x20_P2.54mm_Vertical | C50984
0.22uF | C2,C30 | C_0805_2012Metric | C5378
22uF | C18,C19 | C_0805_2012Metric | C602037
APCI0108-P001A Teensy_4.0_MicroMod | U40 | 21992304 | C841659
MPR121, 0x5A | U45 | UQFN-20_3x3mm_P0.4mm | C91322
MountingHole | H10 | MountingHole_3.2mm_M3
MountingHole | H11 | MountingHole_3.2mm_M3
MountingHole | H12 | MountingHole_3.2mm_M3
MountingHole | H9 | MountingHole_3.2mm_M3
MountingHole | H6 | MountingHole_3.2mm_M3

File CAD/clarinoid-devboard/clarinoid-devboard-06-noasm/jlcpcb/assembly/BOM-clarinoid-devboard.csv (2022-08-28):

Comment | Designator | Footprint | LCSC
captouch 3x3x1 header B | J13,J14,J15,J17,J18,J19,J21,J24,J25,J26,J27,J9 | PinHeader_1x06_P2.54mm_Vertical | C492405

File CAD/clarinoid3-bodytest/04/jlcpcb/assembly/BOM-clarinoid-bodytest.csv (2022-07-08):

Comment | Designator | Footprint | LCSC
PCM5102A | U4 | TSSOP-20_4.4x6.5mm_P0.65mm | C107671
microSD SOFNG TF-15x15 | J11 | SOFNG TF-15x15 (LCSC C111196) | C111196
2.2uF | C4,C5,C6,C9 | C_0402_1005Metric | C12530
WS2812_HEADER LH to external | U9 | PinHeader_1x03_P2.54mm_Vertical_SMD_Pin1Right | C146243
0.1uF | C23 | C_0603_1608Metric | C14663
0.1uF | C10,C11,C13,C14,C2,C26,C27,C28,C29,C3,C31,C32 | C_0402_1005Metric | C1525
10uF | C1,C12,C15,C16,C17,C7,C8 | C_0402_1005Metric | C15525
220R | R6 | R_0805_2012Metric | C17557
470R | R7 | R_0805_2012Metric | C17710
47R | R8,R9 | R_0805_2012Metric | C17714
Injoinic IP5306 battery charge | IC2 | SOIC127P599X155-9N | C181692
0.22uF | C20 | C_0603_1608Metric | C21120
1N4148WS | D1 | D_SOD-323 | C2128
2R | R10 | R_0603_1608Metric | C22977
22R | R1,R2,R3 | R_0402_1005Metric | C25092
470R | R4,R5 | R_0402_1005Metric | C25117
10k | R11,R15,R19,R35 | R_0402_1005Metric | C25744
75k | R16,R20,R36 | R_0402_1005Metric | C25798
4.7k | R17,R18 | R_0402_1005Metric | C25900
5.1k | R13,R14 | R_0805_2012Metric | C25905
25% | D2,D3,D4,D5 | LED_0402_1005Metric | C264424
header i2c pressure | J1,J14,J18,J2 | PinHeader_1x04_P2.54mm_Vertical_SMD_Pin1Right | C2718488
M.2 riser 2.5mm | H1 | Sinhoo SMTSO2530CTJ | C2915630
sw_batteryindicator | SW1,SW6 | XKB switch jlcpcb SW_TS-1187A-B-A-B | C318884
XKB_U262-16XN-4BVC11 USB-C recept | J5 | USB_C_Receptacle_XKB_U262-16XN-4BVC11 | C319148
OLED_HEADER | J9 | PinHeader_1x07_P2.54mm_Vertical_SMD_Pin1Right | C358721
1uH | L1 | Inductor_MCS0630-1R0MN2 | C385251
TLV75533PDBV | U5 | SOT-23-5 | C404027
TLV75733PDBV | U7 | SOT-23-5 | C485517
6N138 | U6 | DIP-8_W7.62mm | C571211
22uF | C18,C19,C21,C22,C24,C25 | C_0603_1608Metric | C59461
APCI0108-P001A Teensy_4.0_MicroMod | U2 | 21992304 | C841659
sw_RHx1 | SW2,SW3,SW4,SW5 | MB2511S2G45 | C84931
PCA9554APW,118 | IC1,IC3 | SOP65P640X110-16N | C86803
0.5R | R12 | R_0402_1005Metric | C880273
MPR121, 0x5A | U10,U11,U8 | UQFN-20_3x3mm_P0.4mm | C91322
SW_y2 | SW14 | PinHeader_1x02_P2.54mm_Vertical_SMD_Pin1Right
encoder header | J21 | PinHeader_1x05_P2.54mm_Vertical_SMD_Pin1Right
SW_x2 | SW11 | MB2511S2G45
SW_OK | SW7 | solder point DIP 1x2
I2C HEADER main to PITCH | J7 | PinHeader_1x04_P2.54mm_Vertical_SMD_Pin1Right
main header multi to LH | J12 | PinHeader_1x07_P2.54mm_Vertical_SMD_Pin1Right
WS2812B | D8 | LED_WS2812B_PLCC4_5.0x5.0mm_P3.2mm
SW_y1 | SW13 | PinHeader_1x02_P2.54mm_Vertical_SMD_Pin1Right
clarinoid3 DAC and POT subboard interconnect | J19 | Bourns_POT_PTR902-2020K-A103 Panel interconnect
clarinoid3 main usb interconnect 12p | J13 | clarinoid3-sd subboard castellated
WS2812B | D16 | LED_WS2812B_PLCC4_5.0x5.0mm_P3.2mm
RH touch keys header | J6 | PinHeader_1x04_P2.54mm_Vertical_SMD_Pin1Right
WS2812B | D7 | LED_WS2812B_PLCC4_5.0x5.0mm_P3.2mm
WS2812B | D25 | LED_WS2812B_PLCC4_5.0x5.0mm_P3.2mm
SW_BACK | SW9 | solder point DIP 1x2
LH header multi to main | J10 | PinHeader_1x07_P2.54mm_Vertical_SMD_Pin1Right
NetTie_2 | NT2 | NetTie-2_SMD_Pad0.5mm
SW_x3 | SW12 | MB2511S2G45
WS2812B | D17 | LED_WS2812B_PLCC4_5.0x5.0mm_P3.2mm
SW_x1 | SW10 | MB2511S2G45
octave_keys_6 | U12 | CLARINOID_M6_6OCTAVES_p13.3_offset1.0mm
clarinoid3 DAC and POT subboard interconnect | J15 | Bourns_POT_PTR902-2020K-A103 Panel subboard castellated header
PTR902-2020K-A103 | R21 | PTR902-2020K-A103
clarinoid3 main usb interconnect 12p | J17 | clarinoid3-sd subboard smd

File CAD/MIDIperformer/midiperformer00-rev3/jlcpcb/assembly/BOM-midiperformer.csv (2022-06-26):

Comment | Designator | Footprint | LCSC
0.1uF | C1,C2 | C_0603_1608Metric | C14663
220 | R1,R2 | R_0603_1608Metric | C22962
330 | R10,R11,R12,R13,R14,R15,R16,R9 | R_0603_1608Metric | C23138
470 | R7,R8 | R_0603_1608Metric | C23179
47 | R3,R4,R5,R6 | R_0603_1608Metric | C23182
L7805 | U3 | TO-252-2 | C54285
6N138 | U1,U2 | DIP-8_W7.62mm | C571211
1N4148 | D1,D2 | D_SOD-123 | C81598

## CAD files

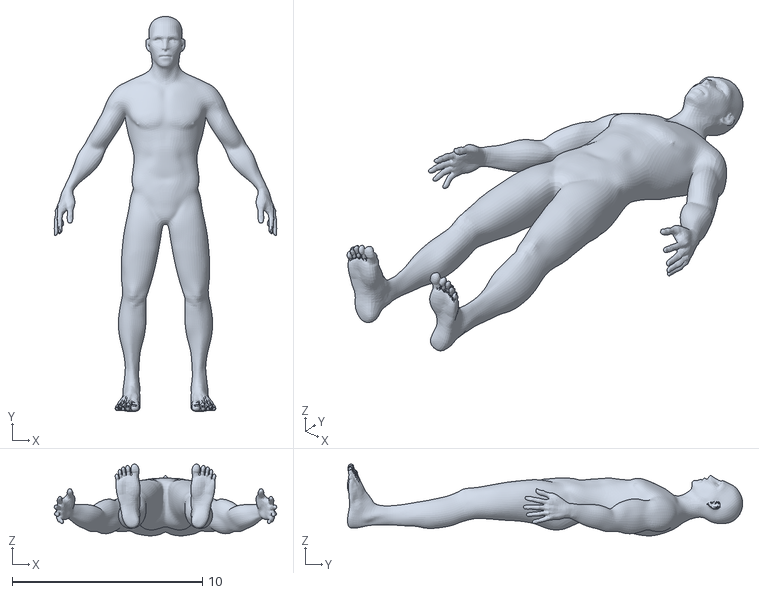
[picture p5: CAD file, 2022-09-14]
CAD/bommanoid/fdx54mtvuz28-FinalBaseMesh/FinalBaseMesh.obj
11.7 x 20.7 x 3.77

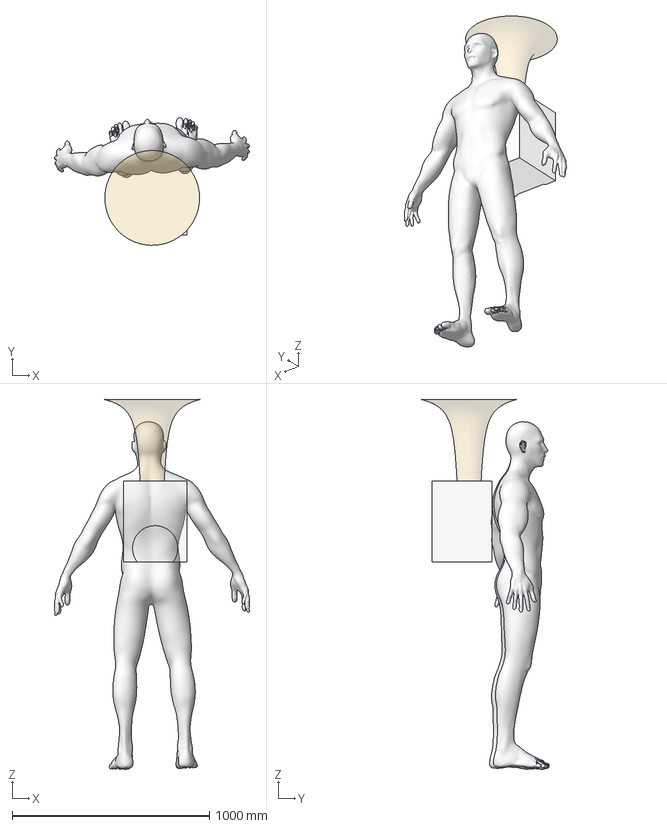
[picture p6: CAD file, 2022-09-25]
CAD/bommanoid/speakercab2.FCStd
988.2 x 646.2 x 1873.6 mm
bell
FinalBaseMesh

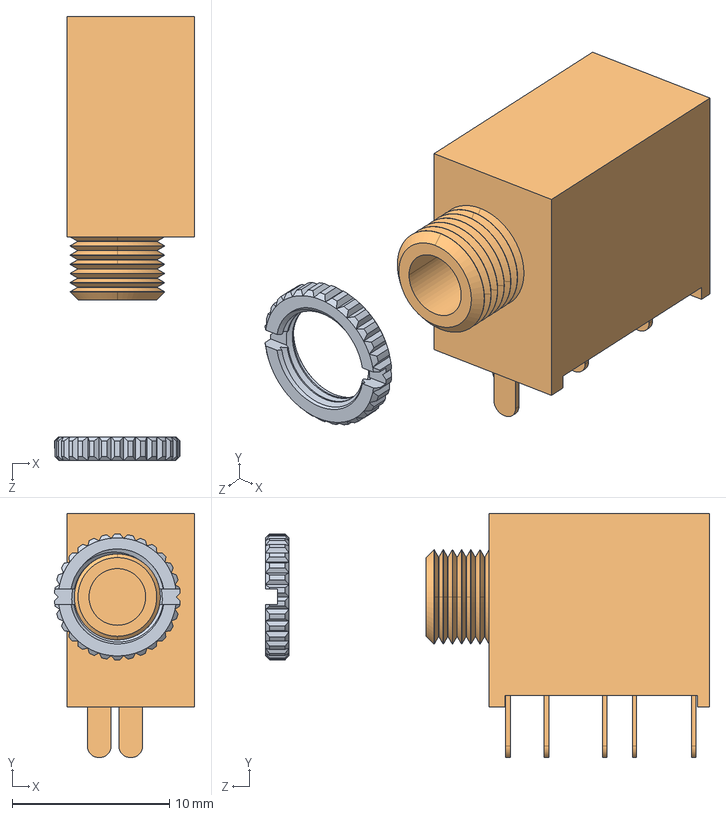
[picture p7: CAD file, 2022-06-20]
CAD/models/35RAPC4BV4.step
8.89 x 15.5 x 28.2 mm

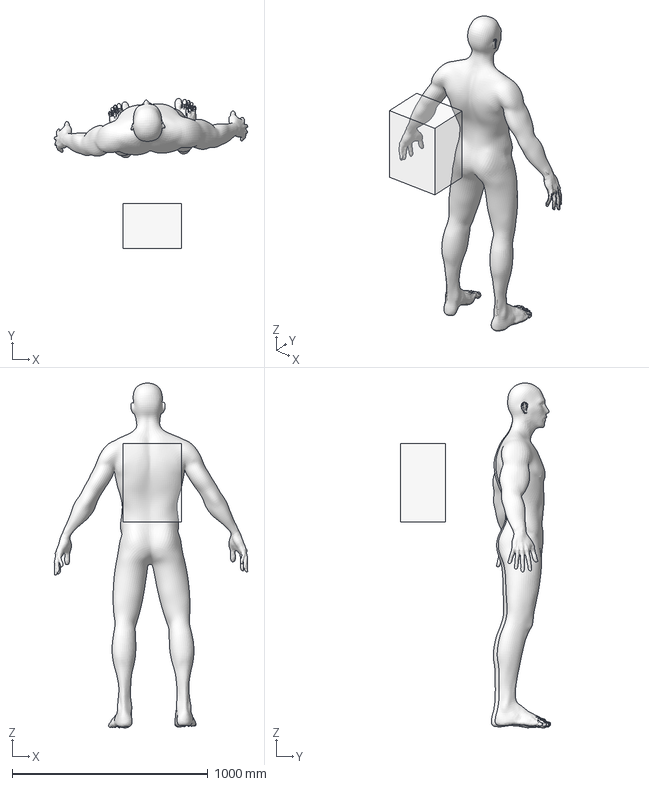
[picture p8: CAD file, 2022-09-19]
CAD/bommanoid/speakercab1.FCStd
988.2 x 767.2 x 1761.2 mm
FinalBaseMesh

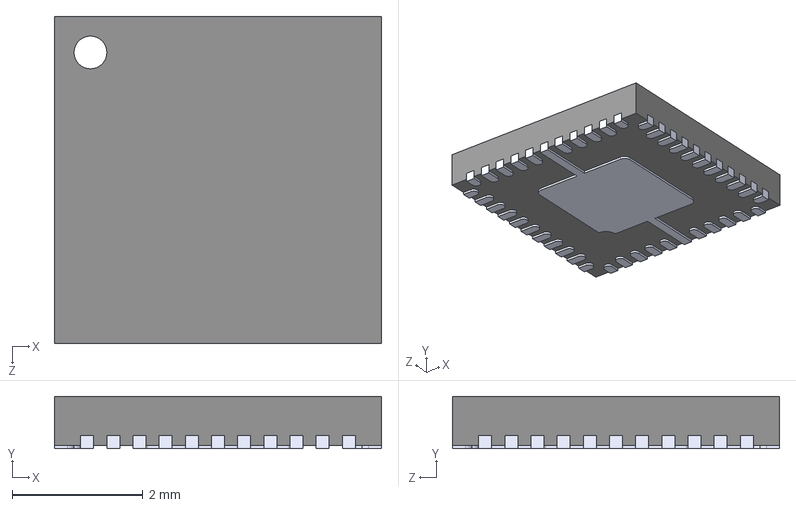
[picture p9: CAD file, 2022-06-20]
CAD/models/IS31FL3236-QFLS2-TR.step
5.00 x 0.8 x 5.00 mm

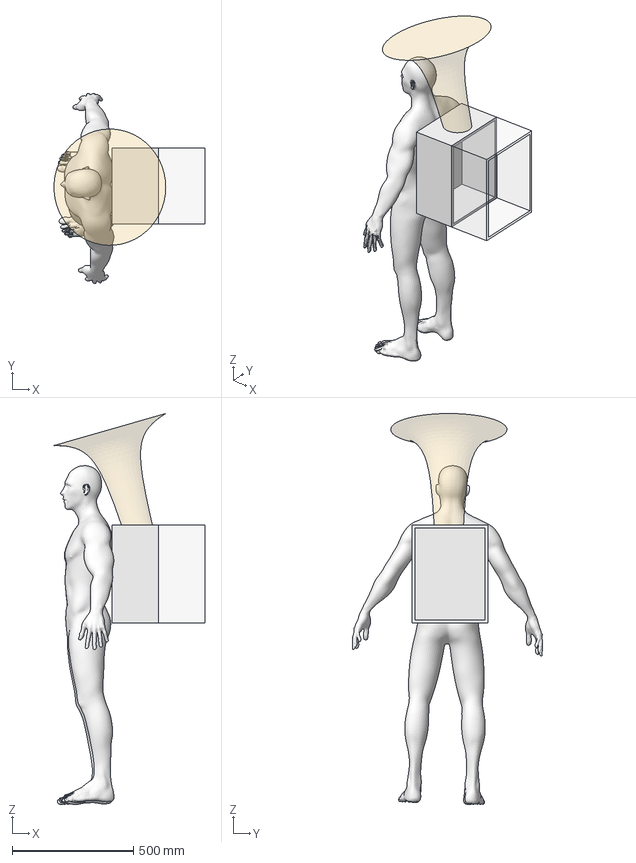
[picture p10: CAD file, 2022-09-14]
CAD/bommanoid/ideal.FCStd
622.7 x 785.8 x 1613.4 mm
bell003
FinalBaseMesh002

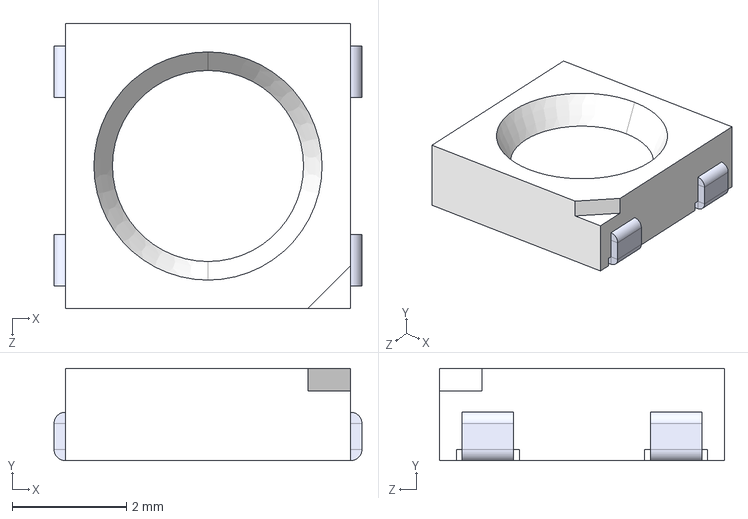
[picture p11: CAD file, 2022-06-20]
CAD/models/WS2812B-B.step
5.40 x 1.62 x 5.00 mm

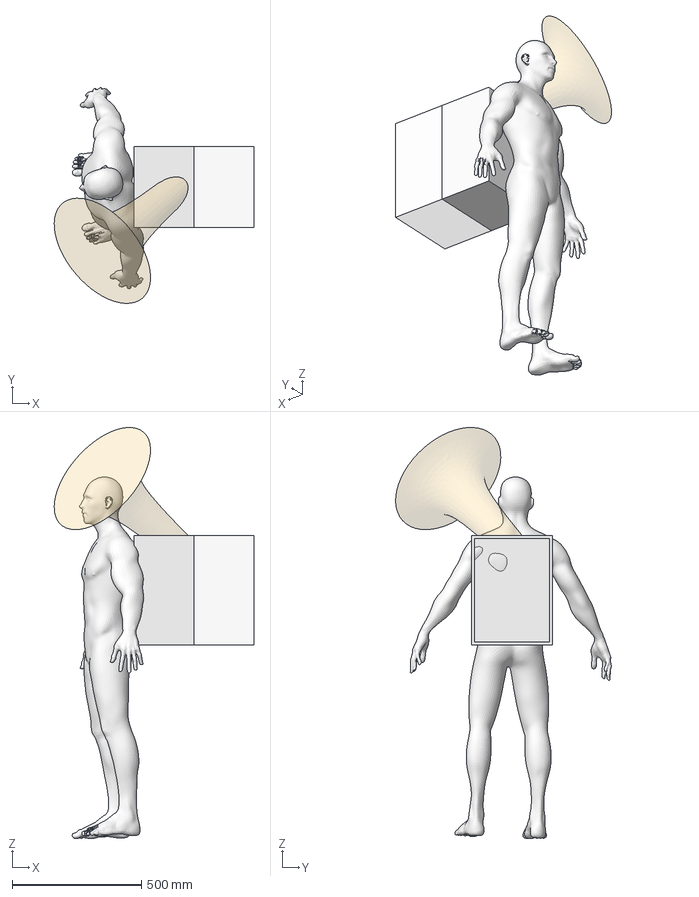
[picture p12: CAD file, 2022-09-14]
CAD/bommanoid/sketch1.FCStd
772.0 x 834.5 x 1589.5 mm
bell
FinalBaseMesh

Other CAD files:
CAD/bommanoid/korgmicrokey37.FCStd

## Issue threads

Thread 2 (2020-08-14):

pitch down is wrong orientation

thenfour, 2020-08-14:

thenfour, 2020-08-15:
fixed in the physical prototype

Closed 2020-08-15.

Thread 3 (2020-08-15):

Cap touch sometimes has spiky readings (grounding issue)

thenfour, 2020-08-15:
Need to have a ground plate to smooth out some noise, otherwise keys will occasionally go crazy and require grounding again.

Closed 2020-08-15.

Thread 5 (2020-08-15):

figure out bite sensor

thenfour, 2020-08-15:
need to find a way to measure pressure without the breath affecting it. maybe this is why akai chose magnetic sensing

thenfour, 2020-08-30:
here's an idea: use 2 air tubes from the mouthpiece: one which is static, and one that you can close by biting it to close it off. the difference in pressure would determine how much you're biting.

worth trying the magnetic sensing idea too, but not sure how physically to acheive it.

thenfour, 2020-09-26:
closing because i think it's too precarious using my build methods to do this in the mouthpiece. much more reliable to use RH thumb to achieve this control.

Closed 2020-09-26.

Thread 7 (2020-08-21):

mk1 touch keys are unstable

thenfour, 2020-08-21:
We don't want mk1 to be totally abandoned so we should resolve this.

- reset keys command does seem to work, but doesn't resolve jumpiness.
- in general certain keys are just slow to respond. i think smarter logic needs to be implemented for example LH4.
- after a while, keys can start to "flicker". reset all keys doesn't usually help.
- sometimes flickering is influenced by touching a neighboring key. problem with physical build, or problem with thresholding?
- touch key graphs show tons of noise when keys are touched. problem with graph or keys?

some ideas / considerations;
- we skip like 75% of all serial packets incoming. packet size is only 22 bytes, so not sure why exactly but maybe just switch to easytransfer_i2c? Breath seems very stable though so i don't think this is the issue.
- we could even just go straight to using the mpr121 boards for this, though it's some work. i would want to wire directly to the T4.

thenfour, 2020-09-13:
plenty of ideas, just want to get it usable. mostly right now the "reset keys" thing seems to just not work. intermittent issues though

thenfour, 2020-10-10:
it won't be used for reliable performances; it's mostly for experimentation etc. and when mk2 is done it's not even likely to be used ever. this is not an issue of software that would be used for mk2 so i'm closing this until it's proven needed after mk2 is available.

Closed 2020-10-10.

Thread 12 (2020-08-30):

put a battery inside this thing (mk2)

thenfour, 2020-08-30:
it means cutting the Vin/Vusb lines

https://www.pjrc.com/teensy/external_power.html

https://forum.pjrc.com/threads/33009-Using-External-Power-for-Teensy

send usb power to the battery vin, and send battery vout to the vout of the teensies.

thenfour, 2020-09-03:
changing to mk2 because  mk1 too fragile and doesn't match the physical build of target; it would be a waste of time.

Closed 2020-10-05.

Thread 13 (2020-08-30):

screen needs to be visible (mk2)

thenfour, 2020-08-30:
having visual feedback would be extremely helpful for confirming actions of extra buttons, selecting scales, knowing which layer/patch/whatever is selected, etc.

thenfour, 2020-09-26:
a guide wire, slot in the pipe, and a removable ribbon cable header works great for this. even dupont connector is reliable

Closed 2020-09-26.

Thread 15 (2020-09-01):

Improve throttling/task scheduling

thenfour, 2020-09-01:
Right now tasks are throttled by milliseconds, and staggered in a very dumb way in a broken attempt to level load.
There may even be a lib out there i should use.
otherwise there are plenty of ideas for this. make throttler a sort of task scheduler, and check timings between tasks to see if we should exit the frame.

--

there are actually a lot of existing task scheduling / multi-tasking managers, but they tend to be too heavy and act like thread schedulers with context switching, yield() etc. What i need is run-to-completion and specify tasks on a rate-limiting way. looks like this one is pretty close, can at least be a model: https://github.com/hideakitai/TaskManager

One target behavior is that low priority things should be run in sequence, with high priority tasks being run in between. And consider if a task is likely to make another one late. All our tasks tend to have pretty constant run time so this should be possible. If something is low priority and would make a higher priority task late, delay it further.

--

Another thing to consider: I don't want to add true threading; it's not necessary. but having a way to split up long-running tasks could be helpful. Tasks can manage how to split that up by themselves, but it then might be important to **guarantee sequential execution**.

thenfour, 2020-12-09:
OK so at first I went with a task manager which considers critical vs normal priorities, estimated timings (so normal pri tasks should not run if they would cause a critical task to be overdue). This worked fine but is overly complex. When critical tasks start to hog time, normal pri tasks will literally never run. Which I could fix, but it's all unnecessary. While debugging other issues, it's best to eliminate "is the task manager causing this?" from the equation.

Latest version of the task manager is a "task planner" where you specify a static execution plan with hard-coded timings. The planner attempts to maintain this timing as well as it can, always looping through the plan so all tasks get run equally.

Closed 2020-12-09.

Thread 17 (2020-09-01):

use mpr121 for cap touch (instead of teensy LC) (mk2)

thenfour, 2020-09-01:
- 2-wire connection and hardware selectable address means it takes no more pins than the LC
- using the SFI and ESI registers, sample rates can be configured down to 4ms
- all thresholds can also be configured. or at very least a soft reset is possible.
- using the mpr121 adafruit library on Teensy 4 @ 600mhz, sampling all 12 electrodes took only 233 microseconds. this almost certainly beats the serial communication speed between the LC. so we're in a win-win.

Closed 2020-10-05.

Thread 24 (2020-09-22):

Support duration multipliers for loop layers (mk2)

thenfour, 2020-09-22:
the idea is: you play a 1-measure bassline, loop.
then you want to add a 2-measure layer on top.
I'm thinking, a button action which does "double loop duration".

adding the underlying functionality should be enough to start experimenting with how this would work UI-wise.

thenfour, 2020-12-13:
closing this until i actually find it's something i'm missing.

Closed 2020-12-13.

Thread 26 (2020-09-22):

Use a true LPF for breath & pitch value smoothing.

thenfour, 2020-09-22:
See MusicalState.hpp:15

// TODO: create a time-based smoother (LPF). throttling and taking samples like this is not very accurate. sounds fine today though.

thenfour, 2021-07-10:
i think it's just not necessary. I found that smoothing should be as small as possible without introducing noise, and we have a very regular task scheduling, so LPF is probably just overkill when we can just hard-code it per device.

Closed 2021-07-10.

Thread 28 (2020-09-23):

Navigating top-level menus needs better visual feedback

thenfour, 2020-09-23:
problem is that it's very hard to understand where you are in the menus; it's just a random sequence of pages, and they all operate differently.

i envision a couple changes:
- when you switch pages, briefly show a small "minimap" showing the current selection
- possibly show a label as well as the minimap, like "2/8 System Settings" so you don't need to consume a bunch of space on the app's front page with the title.
- also unify the front page with a sort of header maybe.
- have an icon for each app type. Settings pages get a gear ⚙. Debug pages get a toolbox or microscope or something 🛠 🔬
- a very quick sliding animation

thenfour, 2021-05-17:
yea this is a very nice-to-have

Closed 2021-05-17.

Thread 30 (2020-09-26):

transition from pitchbend to hands-off or max should latch instead of zeroing

thenfour, 2020-09-26:
the scenario: you are sliding pitch up, and BAM you hit the threshold and we drop straight to pitch=0.
or you are sliding down and your finger slides off the strip.

In either case, it's better to latch the pitch bend than to jump to 0.

i'm thinking that basically, the "hands off zone" is more of a hold zone.

with value smoothing we should be careful; when you transition from 99% (pitch down) to 0% there will likely be some intermediate values from smoothing. rather than examining the raw data, which is just going to be noisy, find another way to delay the latch. like "if we enter hands-off range within N samples, latch the original value" or something. not sure what makes sense.

Closed 2020-10-08.

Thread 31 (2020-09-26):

select new breath sensor

thenfour, 2020-09-26:
i want to avoid analog reads so I2C preferred.

thenfour, 2020-10-05:
In fact I2C is *not* faster than analogRead. AnalogRead is like 17 microseconds while a I2C round trip to ABPMAND001PG2A3 at 1000000 baud = 34 microseconds. This is acceptable. 4-byte read was 55 microseconds round trip.

But there's some hope that a digital interface gives better stability; their ADC should be tuned for their application. We go with this.

Closed 2020-10-05.

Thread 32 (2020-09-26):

select new DAC board

thenfour, 2020-09-26:

thenfour, 2020-10-05:
HiLetgo PCM5102 selected. It sounds good, possibly better than the default teensy board, and it's very compact so it should be able to piggyback the T4.1 in the build.

Closed 2020-10-05.

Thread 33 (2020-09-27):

Measure processing time of note data

thenfour, 2020-09-27:
We propagate these MusicalVoice objects through the system; we could easily measure the time from its generation until it hits the synth state just by adding a micros() call.

What I want to see is: complete time from breath read -> sound output. Consider latency of breath sensor (datasheet says <1ms), plus 128 sample audio buffer (2.9ms).

i think this is probably best left to wait until better task mgmt system. then i will know better how to profile things like this in general.

thenfour, 2020-12-09:
with recent Bassoonoid refactors, a new task manager makes this more structured and there's a new "Performance" menu showing all these timings.

Closed 2020-12-09.

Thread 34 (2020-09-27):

Display temperature somewhere

thenfour, 2020-09-27:
we have the info from multiple sensors, might as well show it.

note: getting extra info like this via I2C does add overhead to the communication.

Closed 2021-05-17.

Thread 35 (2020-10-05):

use WS2812Serial for leds

thenfour, 2020-10-05:
the sample works out of the box with the LEDs I'm using. this library is literally 100x faster than the default adafruit neopixel library. 30 LEDs display in about 7 microseconds rather than >400.

For mk2 because it requires wiring to a serial TX pin.

thenfour, 2020-12-09:
this is now done in bassoonoid and all future clarinoid projects

Closed 2020-12-09.

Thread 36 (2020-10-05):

increase SSD1306 spi speed

thenfour, 2020-10-05:
increase SSD1306 spi speed? https://forum.pjrc.com/threads/47307-Teensy-3-6-with-SSD1351-OLED

quick breadboard test shows the default 8mhz can be bumped to 88mhz, cutting our fastest update time in half, 280 microseconds.

But marking for mk2, because it requires using hardware SPI wiring.

thenfour, 2020-12-09:
at this wiring length, about 1m, plus maybe the fact that i'm using a molex connector, i can't go 88mhz, but 44 is working OK on bassoonoid.

Closed 2020-12-09.

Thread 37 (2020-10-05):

use the 32-bit float fork of teensy audio

thenfour, 2020-10-05:
- use the float fork of teensy audio https://github.com/Tympan/Tympan_Library
    - https://forum.pjrc.com/threads/49977-New-audio-effect-AudioEffectAnalogDelay
    - https://github.com/pteichman/roto2/blob/master/vibrato.cpp

-----

first crack at this and it seemed promising, but the output_i2s class doesn't compile. the float fork is not actually that complete either; missing a lot of things like envelopes, waveforms, verb, etc.. so this would be significant work.

But the benefits would be pretty big, most notably for headroom. Blofeld has the same issue as clarinoid: 16-bit internal processing means you need to leave a LOT of headroom and signals feel either extremely quiet or clipping.

so i want to be able to use the existing `output_i2s` class, but portions of the grid in 32-bit float. Maybe some custom float graph processing is necessary.

good ideas of mixing 32-bit and 16-bit processing: https://forum.pjrc.com/threads/61266-openaudion_arduinoLibrary-not-useable-on-t4-t4-1

also check a t4 version of 32-bit output_i2s from this branch of tympan: https://github.com/Tympan/Tympan_Library/blob/feature_Teensy4_SD_ble/src/output_i2s_f32.cpp

-----

this is still not something i'm certain about doing. The current processing actually sounds pretty good and there's not much reason, sound-quality-wise to upgrade to 32-bit. Headroom is a real concern but a very small one. so far it doesn't disrupt me.

The biggest reason to use 32-bit is for modulations, but even that can be very easily workedaround by just scaling things.

#96 is about optimization and currently we're at 100% CPU at 7 voices. So switching to 32-bit is premature unless we can free up CPU

-----

let's close this for some reasons:

* some things, like oscillators, actually WANT to be in fixed-point. other things lik emodulation signals can be less-than-audio-rate. so basically, there's no good reason to lock the graph into being 32 float.
* what is the *actual* value? better audio quality for some things, but ultimately there's no actual *problem* with audio quality so there's minimum value
* and the cost is CPU, potentially a lot. With polyphony, now we want as much CPU free as possible.

thenfour, 2021-07-21:
NOTE: the latest fork i should be using is here: https://github.com/chipaudette/OpenAudio_ArduinoLibrary

Closed 2022-12-01.

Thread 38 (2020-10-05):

New interval type for harmonizer: Approximately X chromatic semitones

thenfour, 2020-10-05:
The problem is not all scale types have the same distances between their degrees. In particular if you switch from Major pentatonic to Major normal, it will mess up your voicings in a way you don't really expect, even when they contain the same notes.

So instead of just blind "scale degrees", better to support "approximately N absolute interval". So you want a 5th down, we always give you a 5th down as long as its in the scale. If its'not, then options can be applied:

* Nearest-favoring-up
* Nearest-favoring-down

Closed 2021-05-17.

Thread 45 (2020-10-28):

Implement button assignments

thenfour, 2020-10-28:
new clarinoid versions have tons of buttons which are meant to be assignable. They are all momentary buttons, and I want a lot of flexibility as i experiment with ergonomics. so i'm thinking

- Button assignment submenu (each button + modifier combo)
  - Type: momentary, push value, pop value, cycle through value list, modifier1, modifier2, modifier3, etc
  - Action: synth patch, harmonizer patch, loop action, metronome, transpose, verb gain, portamento, or any param within
  - Param: which could be synth patch #, value, etc...
- Axis assignment submenu
  - Dimension: pitch, sync range, filter max, etc, modulation, CC
  - Curve
  - Range in, range out, regions (think pitch)
- Button tester view/app
- Axis tester

Eventually could be interesting for buttons to be used for modulation somehow but let's start with this.

thenfour, 2020-12-13:
the resulting design is actually much more complex than i imagined.
- i wanted all existing functions to be mapped through this
- i wanted physical controls to be configured by individual projects, not global
- i wanted to perform all mappings through this system including unipolar breath with curve, bipolar pitch with its regions, musical keys, encoders, everything
- i wanted to support many-to-many keys to functions. enabling things like mapping shift+encoder for fine mapping
- i wanted to support modifier keys

Closed 2020-12-13.

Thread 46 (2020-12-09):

Better fault handling / debugging

thenfour, 2020-12-09:
- fault handilng: https://interrupt.memfault.com/blog/cortex-m-fault-debug#relevant-status-registers
  - teensy debugging: https://github.com/ftrias/TeensyDebug

Also: Note that debugging is slightly less necessary if we just have good test hardware. The live instrument is awkward and risky sometimes to experiment on, so let's create dev boards which are optimized for desktop use, easy access to components, repairable, not used on stage.

thenfour, 2021-08-16:
teensyduino 1.54 includes fault handler which does a reset, and CrashReport which can help detect a fault, report it, and it means we can almost guarantee never having to disassemble the clarinoid to hit the program button. so, closing this.

Closed 2021-08-16.

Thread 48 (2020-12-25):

Upgrade DSP (filters, reverb, tape delay...)

thenfour, 2020-12-25:
I'd love to improve DSP for:
- sound quality
- ability to visualize for example the filter curve as you edit params

but this should come after:
- synth plumbing is more developed (better modulation system etc)
- synth operates on float samples
- i'm able to do things in test environment
- more param editing fundamentals are in place (dual pole mapping)

not sure how to improve the reverb, but there's GVerb https://github.com/highfidelity/gverb
filters: https://github.com/vinniefalco/DSPFilters

thenfour, 2021-05-17:
for bassoonoid at least, this is pretty much done. don't bother with reverb.

Closed 2021-05-17.

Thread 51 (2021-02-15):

get metronome app working again

thenfour, 2021-02-15:

thenfour, 2021-05-26:
a few things happen with this change:

- metronome was broken because we were treating milliseconds as microseconds so it was total chaos
- the metronome settings app was using old style code and needed to be updated
- now we make the distinction between LED enable and sound enable
- adding support to display this by LED (with decay, brightness)
- also adding a toggle switch for it

Closed 2021-05-26.

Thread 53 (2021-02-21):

Sometimes MCP23017 becomes unstable or extremely slow

thenfour, 2021-02-21:
This has been a persistent issue with MCP23017, and at some point I had concluded that it's when a TX/RX error happens with the I2C interface. The comm just craps out and the device subsequently goes sorta haywire, causing anything from very long comm times to total lockup.

I had at some point scoped the signal and found pull-up resistors that made a better curve but at the expense of less energy efficiency. Don't even remember which resistance at this point.

But occasionally I still do see this issue and I can only imagine it's because either the resistors are still not enough, or because of anomalies in signal elsewhere (I2C is just not very robust in this way; once a single tx gets boned, it's lost).

thenfour, 2021-05-17:
Fixed by correcting bad soldering.

Closed 2021-05-17.

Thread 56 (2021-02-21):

General filter work

thenfour, 2021-02-21:
OK this is important. The whole deal is breath. Breath breath breath controller. Everything in the character of the sound is controlled by breath. Breath controls a single thing: filter.

It is therefore critical that we have precise control over a high quality filter. Originally using the teensy SVF filter, but I want to try other filters for variety, and because the teensy library has a typically mediocre sound/musical quality to it.

The teensy's built-in Biquad filter however has problems in the way I automate it. In low frequencies it goes crazy, signal .
I also tried importing a couple biquad implementations from the net and they have similar issues.

So it's time to bring it into the test app and make a small collection of worthy filter implementations to add to the project.

thenfour, 2021-02-26:
New compound filter types added in latest commit with saturation, Q, cutoff.

Closed 2021-02-26.

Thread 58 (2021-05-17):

"Hold pitch" / "hold fingering" function is needed

thenfour, 2021-05-17:
The problem: While playing, both hands are occupied. When directing a band this is a problem because i don't have any way of giving expressive cues or marking time.

Proposed solution: A button which can toggle a "pitch hold". When on, the fingering played is locked in. This way both hands are free'd as long as i don't mind playing the same note.

And bonus: keys should still operate so i can actually still change pitch, but it will be relative to the locked pitch instead of C#.

Closed 2021-05-22.

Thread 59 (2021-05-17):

quicker startup

thenfour, 2021-05-17:
because of the need to sometimes reset the device mid-performance, startup needs to be INSTANT

Closed 2021-05-22.

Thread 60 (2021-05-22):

Use default wire/i2c bus speeds to eliminate this as a possible failure point

thenfour, 2021-05-22:
The faster speeds are great for freeing up the CPU, but i'm experiencing sometimes instability during rehearsals so i want to just try going back to default (quite slow) speeds and eliminate this as a source of the problem. Well it could also just make it harder to repro the "true" problem but this is OK for the moment as I gear up to make an improved bassoonoid with improved wiring and shielding and strapped-down hardware.

Closed 2021-05-22.

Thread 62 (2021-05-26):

numeric editor text is grayed out sometimes even when it's writable

thenfour, 2021-05-26:
seems that the `mSolidText` flag is not being reset properly, so when the last menu item on the screen is grayed, then the editor of the current item will be grayed.

Closed 2021-05-26.

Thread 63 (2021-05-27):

Display apps scrolling into negative selects the wrong app

thenfour, 2021-05-27:
steps to repro:

- have multiple display apps (bassoonoid1)
- encoder scroll display apps in reverse direction, scroll before app 0.

we expect to wrap around to the end of the list. But instead it wraps to some other random app. Some apps are no longer accessible.

Issue was with C++ operator %. Switched to using RotateIntoRange

Closed 2021-05-27.

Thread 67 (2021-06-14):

Breath filter mapping is not ranged correctly.

thenfour, 2021-06-14:
You should be able to hear perfectly smooth filters, but i'm hearing a hard cutoff in the lower range.
I think the issue is that we have a "note on threshold" as well as a "min breath pressure threshold". I think in theory at some point these made sense, because we didn't want to trigger note ons too aggressively or we fill up the loopstation. However the "is note on" logic is so prevalent we depend on it, and the two values should really be the same.

Closed 2021-06-14.

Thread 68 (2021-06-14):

Add chorused reverb & delay to fx chain

thenfour, 2021-06-14:
it's just such a nice sound

thenfour, 2021-07-10:
the chorus part i think i should live without for a while; current master fx (just delay + reverb) sounds pretty good.

Closed 2021-07-10.

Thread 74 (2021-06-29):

Control mpr121 baseline function from menus

thenfour, 2021-06-29:
Every once in a while, baseline jumps way up seemingly randomly and you have to wait a long time for it to fall back down. Would be nice to control the ECL register from menus:

- To disable baseline tracking (locking in the current baseline)
- To reset baseline to current values
- Possibly to control the baseline filtering, but don't really care. It would be nice to just have a button that can reset the electrode calib.

Closed 2021-06-30.

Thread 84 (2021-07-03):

figure out how FM will work.

thenfour, 2021-07-03:
oscillators will need envelopes only for modulation use

-------

let's go for something a bit more workflow-oriented. I think fm support can be added with just 2 additional params:

* FM Algo - selecting which oscillators are carriers & which are modulators
* FM Feedback - controls a feedback modulation for each osc.

When an oscillator is a modulator, it is no longer routed out as an audible signal. It's automatically routed through a modulation based on the FM algo.

Otherwise everything is the same for the user.

Regarding the signal, it doesn't pass through the breath filter before routing back into the modulation matrix, so you get a clean constant signal which you can modulate with envelopes etc.

If this feels too awkward, it may be interesting to consider adding an amplitude envelope to modulators, but for a 1st POC it's not necessary.

thenfour, 2021-07-21:
need to remember that the FM synths I'm used to (yamaha) are not actually freq modulation, they are phase modulation. I believe this accounts for the confusion / errors. It's also simpler in concept because frequency is in Hz, whereas phase is always 0-1 which corresponds well to an incoming modulator.

thenfour, 2021-07-21:
at this point FM is working pretty well and the only problems left are regarding limitations of modulation. for example if you modulate amplitude, you are always multiplying by the modulator so the resulting wave :

1. can never be louder than the original (not a big deal, just a note)
2. can never be non-zero when the modulator is zero.

2 is important because for example if you want a baseline amplitude then you're out of luck. this feels like a common case.

Another problem with FM I'm finding is that it's so dependent on attacks. FM'ed waves add brightness, and this is mostly associated with attacks. Think FM slap bass, EPiano, marimbas... Sustaining FM instruments tend to have a very common sound. The variety of FM synthesis feels concentrated in the attack.

Basically, what's the role of breath in an FM instrument? Hard to say so far. I think this will need more experimenting.

Closed 2021-07-21.

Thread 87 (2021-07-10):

Audible pop/click when changing synth patches

thenfour, 2021-07-10:
need some kind of volume ramp when changing synth patches somehow, or some smooth transition somewhere.

the filters indeed pop; and definitely solving this in the filter would solve for all. A state reset is probably necessary, but with some smoothing or a volume ramp or something.

thenfour, 2021-07-18:
latest change is a fairly superficial solution: just ramping up when filter type changes.
there are still pops when the filter type doesn't change, and when there's audible material during a patch change.
but let's give it time to see if this is sufficient.

thenfour, 2021-07-30:
rehearsal yesterday: did not hear this anymore.

Closed 2021-07-30.

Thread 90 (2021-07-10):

Make voices polyphonic

thenfour, 2021-07-10:
would like to allow a release stage on envelopes, implying polyphony per voice. i think it will need to be specified as mono/poly in settings, not only based off env settings.

plus, with the current breath filter setup, what is the envelope actually controlling? breath filter cutoff? i think it's the only way that makes much sense.

depends on #96

-----------

After a bit of thought: Breath control is an envelope. There is a basic assumption that "no breath, no note". We give it more shape by automating filters etc, but ultimately when the breath stops, the note stops. So I'm thinking that we make a way to control the "breath envelope" more like a normal envelope. The sustained breath signal is really an envelope sustain level. So we can add:

* Attack time
* Release time

thenfour, 2022-10-09:
recently implemented, but only for keyboard instruments. for clarinoid not yet possible but it will come as i adapt keyboard to support clarinoid.

Closed 2022-10-09.

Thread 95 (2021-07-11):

experiment with a small delay to avoid glitch notes

thenfour, 2021-07-11:
the touch key system is so responsive that it doesn't forgive much. which is great for practice, but maybe it's TOO responsive for performance.

very curious to see if a tiny delay (<5ms) could help avoid "glitch" notes; any notes that only last <N ms are discarded.

Also curious to scale that by distance. So small intervals get like 3ms tolerance, big intervals which are indicative of octave key glitching and less likely to actually be correct get bigger intervals like 10ms.

----------------

I can already tell that the issue is probably augmented by the fact that musical frames are something like 5ms, with all the processing we do. And these little glitchy notes are indeed 1-2 frames long.

----------------

ok so i did this by frames, which is kinda shaky, but so far works. and the scaling by interval thing actually seems to be helpful, but needs to be balanced. so there's really maximum & minimums that are used in the right contexts.

thenfour, 2021-07-18:
first crack at this feels useful, but i don't like that note ons get delayed but breath does not. need to use a real delay; shouldn't be a problem because we're not dealing with many frames of delay.

thenfour, 2021-07-18:
latest version of this now has a couple improvements:
- more simplified & accurate state calc
- refined settings after play test
- only during note transition, this helps soft attacks on new notes

Closed 2021-07-18.

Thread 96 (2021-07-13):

Optimize oscillators & filters

thenfour, 2021-07-13:
Currently they both use 32-bit processing internally and are extremely heavy & unoptimized. Currently we're limiting polyphony to about 6 voices in order to not max out the CPU. If we want polyphonic playing (release env stage) then we need AT VERY LEAST 8 voices. But more like 12+, in order to support harmonizer / looper.

Each voice engages 3 oscillators and 2 filters, and it's definitely a bottleneck. True 16-bit processing of filter would probably be the most savings, but I think it's not going to be reasonable because of the black magic of how they work. Maybe worth giving it a try though.

The most fundamental optimization is to actually NOT `transmit` or `receive` when you know the output buffer will be silent.

thenfour, 2021-08-05:
using https://github.com/romeric/fastapprox,
some benchmarking shows:

* ::powf() = 81 ms
* fastpow() = 20 ms (~4x faster)
* fasterpow() = 9 ms (~9x faster)

that's good news for modulations because i think it will be feasible to permit response curves.

thenfour, 2021-08-06:
Another adhoc benchmark: 100,000 sin() calculations:
* sinf 334 millis
* arm_sinf32 10 millis
* fastsinfull 11 millis
* fastersinfull 9 millis

conclusions:
- absolutely never use sinf().
- fastersinfull is faster but not significantly faster than arm_sinf32.
- fastsinfull can be slower than arm_sinf32. so never use it either.

thenfour, 2021-08-06:
More benchmarks for log().

- log10f 343 millis; a=0.02
- log/ln10 496 millis; a=0.02
- fastlog/ln10 139 millis; a=0.02
- fastlog2/log2of10 134 millis; a=0.02
- fasterlog/ln10 90 millis; a=0.02
- fasterlog2/log2of10 90 millis; a=0.02

code for this:
```
    constexpr size_t iterations = 1000000;

    {
        clarinoid::Stopwatch t;
        float a = 0;
        for (size_t i = 0; i < iterations; ++i)
        {
            a += ::log10f(float(i + iterations / 9) / iterations * 2);
        }
        Serial.println(String("log10f ") + (int)t.ElapsedTime().ElapsedMillisI() + " millis; a=" + (a / iterations));
    }

    {
        clarinoid::Stopwatch t;
        float a = 0;
        for (size_t i = 0; i < iterations; ++i)
        {
            a += ::log(float(i + iterations / 9) / iterations * 2) / 2.30258509299f; // ln(10)
        }
        Serial.println(String("log/ln10 ") + (int)t.ElapsedTime().ElapsedMillisI() + " millis; a=" + (a / iterations));
    }

    {
        clarinoid::Stopwatch t;
        float a = 0;
        for (size_t i = 0; i < iterations; ++i)
        {
            a += ::fastlog(float(i + iterations / 9) / iterations * 2) / 2.30258509299f; // ln(10)
        }
        Serial.println(String("fastlog/ln10 ") + (int)t.ElapsedTime().ElapsedMillisI() +
                       " millis; a=" + (a / iterations));
    }

    {
        clarinoid::Stopwatch t;
        float a = 0;
        for (size_t i = 0; i < iterations; ++i)
        {
            a += ::fastlog2(float(i + iterations / 9) / iterations * 2) / 3.32192809489;
        }
        Serial.println(String("fastlog2/log2of10 ") + (int)t.ElapsedTime().ElapsedMillisI() +
                       " millis; a=" + (a / iterations));
    }

    {
        clarinoid::Stopwatch t;
        float a = 0;
        for (size_t i = 0; i < iterations; ++i)
        {
            a += ::fasterlog(float(i + iterations / 9) / iterations * 2) / 2.30258509299f; // ln(10)
        }
        Serial.println(String("fasterlog/ln10 ") + (int)t.ElapsedTime().ElapsedMillisI() +
                       " millis; a=" + (a / iterations));
    }

    {
        clarinoid::Stopwatch t;
        float a = 0;
        for (size_t i = 0; i < iterations; ++i)
        {
            a += ::fasterlog2(float(i + iterations / 9) / iterations * 2) / 3.32192809489;
        }
        Serial.println(String("fasterlog2/log2of10 ") + (int)t.ElapsedTime().ElapsedMillisI() +
                       " millis; a=" + (a / iterations));
    }

```

thenfour, 2021-08-07:
OK more experiments. this time with converting between float / int16 sample buffers.
very surprising to see that intrinsic ARM ops are sometimes slower than just typical C code.

* manual q15->float micros: 296428
* arm_q15_to_float micros : 99384
* manual float->q15 micros: 124051
* arm_float_to_q15 micros : 257397

Conclusions:
* arm_q15_to_float  is 3x faster than manual copy
* manual copy is 2x faster than arm_float_to_q15

```
    static constexpr size_t iterations = 50000;

    clarinoid::Stopwatch sw;

    srand(micros());

    {
        sw.Restart();
        for (size_t it = 0; it < iterations; ++it)
        {
            sw.Pause();
            for (size_t i = 0; i < 128; ++i)
            {
                int r = rand();
                pq[i] = *((int16_t *)&r);
            }
            sw.Unpause();
            for (size_t i = 0; i < 128; ++i)
            {
                pf[i] = clarinoid::Sample16To32(pq[i]);// (float)pq[i] / 32767.0f;
            }
        }
        Serial.println(String("manual q15->float micros: ") + (int)sw.ElapsedTime().ElapsedMicros());
    }
    {
        sw.Restart();
        for (size_t it = 0; it < iterations; ++it)
        {
            sw.Pause();
            for (size_t i = 0; i < 128; ++i)
            {
                int r = rand();
                pq[i] = *((int16_t *)&r);
            }
            sw.Unpause();
            arm_q15_to_float(pq, pf, 128);
        }
        Serial.println(String("arm_q15_to_float micros : ") + (int)sw.ElapsedTime().ElapsedMicros());
    }

    {
        sw.Restart();
        for (size_t it = 0; it < iterations; ++it)
        {
            // for (size_t i = 0; i < 128; ++i)
            // {
            //     int r = rand();
            //     pf[i] = (((float)r / RAND_MAX) * 2) - 1;
            // }
            sw.Unpause();
            for (size_t i = 0; i < 128; ++i)
            {
                pq[i] = clarinoid::Sample32To16(pf[i]);// saturate16(int32_t(pf[i] * 32767.0f));
            }
            sw.Pause();
        }
        Serial.println(String("manual float->q15 micros: ") + (int)sw.ElapsedTime().ElapsedMicros());
    }
    {
        sw.Restart();
        for (size_t it = 0; it < iterations; ++it)
        {
            // for (size_t i = 0; i < 128; ++i)
            // {
            //     int r = rand();
            //     pf[i] = (((float)r / RAND_MAX) * 2) - 1;
            // }
            sw.Unpause();
            arm_float_to_q15(pf, pq, 128);
            sw.Pause();
        }
        Serial.println(String("arm_float_to_q15 micros : ") + (int)sw.ElapsedTime().ElapsedMicros());
    }

```

thenfour, 2021-08-08:
Multiplying (gain) operations.

* arm_scale_f32  micros=346,141
* manual float  micros=593,928
* audioBufferCopyAndApplyGain  micros=679,428
* arm_scale_q15  micros=681,103
* arm_scale_f32 with 16-bit roundtrip  micros=2,573,190

more interesting observations:

* operating in float is much faster (2x) than working in 16-bit ints in all cases.
* even the fancy process-2-bitpacked-samples-at-a-time method is not really any faster than the single arm_* call.
* even the naive float multiplication is faster than integer math.
* however, float is not so much faster that a roundtrip from/to 16-bit ints is worth it. that's MUCH slower.
* changing buffer datatype is expensive as hell compared to the multiply op, so don't do it.

conclusions: when applying gain to a buffer,
1. if the node is operating on float, apply the gain to the float buffer using `arm_scale_f32`, not int.
2. if the node is not operating on float basis, use the `arm_scale_q15`. it's the same performance as the fancy method but easier to maintain.

```

    int16_t q15[128];
    float f31[128];
    auto reset = [&]() {
        for (int16_t &e : q15)
        {
            e = (int16_t)((float(rand()) / RAND_MAX * 2 - 1) * 32767);
        }
        for (float &e : f31)
        {
            e = (float(rand()) / RAND_MAX * 2 - 1);
        }
    };
    clarinoid::Stopwatch sw;
    static constexpr size_t iterations = 500000;

    {
        reset();
        sw.Restart();
        sw.Pause();
        for (size_t i = 0; i < iterations; ++i)
        {
            float s = float(i) / iterations * 2 - 1;
            sw.Unpause();
            arm_scale_f32(f31, s, f31, 128);
            sw.Pause();
        }
        Serial.println(String("arm_scale_f32  micros=") + (int)sw.ElapsedTime().ElapsedMicros());
    }

    {
        reset();
        sw.Restart();
        sw.Pause();
        for (size_t i = 0; i < iterations; ++i)
        {
            float s = float(i) / iterations * 2 - 1;
            sw.Unpause();
            arm_scale_q15(q15, s, 0, q15, 128);
            sw.Pause();
        }
        Serial.println(String("arm_scale_q31  micros=") + (int)sw.ElapsedTime().ElapsedMicros());
    }

    {
        reset();
        sw.Restart();
        sw.Pause();
        for (size_t i = 0; i < iterations; ++i)
        {
            float s = float(i) / iterations * 2 - 1;
            sw.Unpause();
            for (float& f : f31) {
                f *= s;
            }
            sw.Pause();
        }
        Serial.println(String("manual float  micros=") + (int)sw.ElapsedTime().ElapsedMicros());
    }

    {
        reset();
        sw.Restart();
        sw.Pause();
        for (size_t i = 0; i < iterations; ++i)
        {
            float s = float(i) / iterations * 2 - 1;
            sw.Unpause();
            auto mul = clarinoid::gainToSignedMultiply32x16(s);
            clarinoid::audioBufferCopyAndApplyGain(q15, q15, mul);
            sw.Pause();
        }
        Serial.println(String("audioBufferCopyAndApplyGain  micros=") + (int)sw.ElapsedTime().ElapsedMicros());
    }

    {
        reset();
        sw.Restart();
        sw.Pause();
        for (size_t i = 0; i < iterations; ++i)
        {
            float s = float(i) / iterations * 2 - 1;
            sw.Unpause();
            clarinoid::fast::Sample16To32Buffer(q15, f31);
            arm_scale_f32(f31, s, f31, 128);
            clarinoid::fast::Sample32To16Buffer(f31, q15);
            sw.Pause();
        }
        Serial.println(String("arm_scale_f32 with 16-bit roundtrip  micros=") + (int)sw.ElapsedTime().ElapsedMicros());
    }

```

thenfour, 2021-09-06:
#122 now opens up the possibility for more optimizations in oscillators:

1. remove oscillators that aren't used
2. process whole buffers instead of switching osc buffers each sample.
3. process samples in 1 fn instead of pre-step, step, post-step.
4. there were other things as well, like we can remove a divide in PreStep where we calculate `dT` even when we know it will always be the same.

thenfour, 2021-09-12:
closing because as of today more optimizations have been put in place, and it's pretty reasonable without going into fixed point math. next round of optimization is possible.

Closed 2021-09-12.

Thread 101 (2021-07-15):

Pitchbend range should be per synth patch

thenfour, 2021-07-15:
yes it's more complex, but reasoning:
- it allows for things like risers
- i like this behavior for harmonizer pitch bend behavior
- nice to have: tendency to snap to semitones. for very large pb ranges, this would allow a sort of chromatic slide. probably a simple curve like this: https://www.desmos.com/calculator/e1izuzepho

Closed 2021-07-18.

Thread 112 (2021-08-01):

integrate formant filter

thenfour, 2021-08-01:
https://github.com/TheWaveWarden/odin2/tree/382505316e393390318332d6a5d8778b1aa3e9e8/Source/audio/Filters

thenfour, 2021-08-01:
nm, it uses biquad which doesn't perform well for clarinoid.

Closed 2021-08-01.

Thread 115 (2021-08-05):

modulations should specify source & destination ranges & curve

thenfour, 2021-08-05:
now using a faster pow() means this is more practical than before, at least for k-rate modulations.

for k-rate, this is feasible. but for a-rate, I don't think it is. even with fastpow it's heavy, for something like modulations. I'm hoping we can avoid any naive sample-by-sample operations for modulation. arm_* block operations are a good rule of thumb as being feasible, and that leaves us with just simple arithmetic like add/multiply. So specifying range may be feasible, but not curves.

And then, block op multiplication works in vectors, a direct analogy to the existing scaleN11 system.

So in other words instead of specifying min/max for src & dest, simply specifying scale seemed to take care of most scenarios. At very least we should solve the need for `mAMMinimumGain`. Just adding an offset will do that, but anyway this is the idea.

-----

thought a lot about this, and i have a few main points to consider when designing this:

* NI Massive and most other synths simply use a `scale` to map X to Y. So scale alone is actually enough to work.
* At the signal level, everything is either -1 to 1, or 0 to 1, without exception. And even 0 to 1 values have no difficulty acting as -1 to 1.
* Using only a scale, mapping destination values are calculated as `y = y + (x * scale)`
* Destinations MUST have user-settable "base" values to modulate.
* Allowing "source range" makes sense, because you might want your breath to only affect a destination within a certain range. However, allowing "destination range" makes no sense because it's always going to be added to a base value. If you want a fixed output minimum, set the base value.
* This must be simple enough to perform using efficient block math operations
* This must also be simple enough to visualize well. If it won't work in a compact and simple visualization, then there's no point making it that complex. It must be recognizable in a simple graphic form.

Seems we will also need more modulation types to really take full advantage of all of this. Like randomness, keytracking, etc.

thenfour, 2021-08-05:
depends on #116

thenfour, 2021-08-12:
The fully-working LUT checked in is a bit slower, starting out around 400micros under the previous benchmark (almost passing), then optimized down to 300 micros (passing) by using 16.16 fixed point format and removing some redundant bounds checking.

thenfour, 2021-08-15:
latest commit completes the feature including unit tests, however i don't want to close it until the GUI is finished, to verify that the design is solid.

thenfour, 2021-08-21:
gui stuff is going to be significant and many things may need revisiting, closing this. currently it's tested and working in clarinoid2

Closed 2021-08-21.

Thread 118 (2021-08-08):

osc PWM input range should use all -1 to 1

thenfour, 2021-08-08:
currently input buffer gets clamped 0,1. but this means LFOs won't behave correctly for PWM

thenfour, 2021-09-06:
i'm wrong, this code confused me:

    mPulseWidth = mPulseWidthTarget01 + fast::Sample16To32(pwm1->data[i]);

in fact we're using the whole -1 to +1 range here because we add it to the base value.

Closed 2021-09-06.

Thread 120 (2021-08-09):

consider deviating Filter parameters for stereo width like we do with delay

thenfour, 2021-08-09:
low priority because i don't really think this is likely to sound useful.

thenfour, 2021-09-12:
i tested this and indeed it doesn't really feel like a compelling sound

Closed 2021-09-12.

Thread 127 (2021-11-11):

Indicate octave using LEDs

thenfour, 2021-11-11:
I find it hard to know which octave I'm fingering before I start playing. It's important to know what I'm going to play before I play it.
AKAI "solves" this with a knurled octave key as a reference. But I don't like this because 1. it's uncomfortable, 2. it actually doesn't help that much. it only helps when your finger is on it.

Solution is to give a visual indication of the octave. A bright ass LED which has acolor associated with octave will work.

Closed 2021-11-11.

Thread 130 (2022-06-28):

oscillators sometimes get into a weird pitch state when using FM

thenfour, 2022-06-28:
not sure what's going on tbh, but sometimes oscillators which are connected with phase modulation get into some oddball state where they are snapping to weird frequencies, often several semitones apart, and not on "real" note boundaries.

I found that when I set phase restart to true, it "snaps out of it" for a while, but will eventually get broken again. Probably some bug in phase accumulator?

Closed 2022-06-30.

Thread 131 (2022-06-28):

gain should not be applied at osc output stage; FM synthesis is broken

thenfour, 2022-06-28:
it's sorta convenient & simple to apply voice oscillator gain at the oscillator itself. but it breaks FM synthesis because it ties output gain to modulation source gain. with FM you want oscillator modulation sources to be totally independent of output gain.

this could be controlled by an "fm algo" which completely disables oscillators, but with the gui i'm planning, better to simply apply gain at the multi mixer stage, after modulations are applied.

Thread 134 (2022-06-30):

k-rate modulations stored in synth voice do not get reset when they should

thenfour, 2022-06-30:
we currently reset them when the patch changes et al, but there's another time they should get reset: when modulation settings change which affect it.

how to repro:

1. create a modulation with breath source
2. while playing breath, remove the modulation.

the internal modulation value will remain high with no ability to reduce it. it should be reset to 0.

Closed 2022-10-10.

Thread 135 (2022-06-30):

portamento not working at all

thenfour, 2022-06-30:
multiple issues with portamento:

first, it wasn't being calculated properly and therefore osc freq was just hanging; fix incoming.

next, there's a problem with timing. The idea behind "time-based" portamento vs "rate-based" is that portamento happens during a fixed duration. Sounds simple but there are some caveats. When you note-on, the timer resets. So rapid notes in a row will just reset the timer and the portamento can take much longer than the duration.

But during that time, pitch bend and other modulations should be able to affect the frequency without portamento being applied. In other words, portamento applies only to the "midi note frequency" part of frequency calculation, not the entire thing.

For this, either portamento must be removed from the oscillator (and into synthvoice where freq is calculated), or the oscillator should become able to calc portamento using an isolated note freq.

Closed 2022-06-30.

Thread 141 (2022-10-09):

add noise oscillator

thenfour, 2022-10-09:
need to think how this will work as well; different noise generators, plus probably some kind of own filtering? fine to copy massive.

if we use a filter here i think it would be best to actually just expand to voices having multiple filters, and different routing options. so you could use a filter for the noise osc, or other, or all.

https://www.musicdsp.org/en/latest/Synthesis/216-fast-whitenoise-generator.html

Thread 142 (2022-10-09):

consider adding filter2

thenfour, 2022-10-09:
the biggest reason to add a filter2 is if we want to support a noise oscillator. then it could use a filter on its own.

various routing options need to therefore be considered. like, are they parallel or serial?

as with so many things, probably just copy massive. oscillators route to one or the other.

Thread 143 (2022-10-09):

note releaseability should account for whether it's physically held

thenfour, 2022-10-09:
currently it doesn't matter if a note is being played due to pedal or physically.
but if you are physically holding a note (think RH + LH), then it should prefer to remain active over others.

Closed 2022-10-09.

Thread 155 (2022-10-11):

add basic midi monitor; fa07 is not working

thenfour, 2022-10-11:
prob misuse of usb host lib; possibly multiple devices and/or usb hub object.

----

edit: use `MIDIDevice_BigBuffer`; source: https://forum.pjrc.com/threads/63681-USB-Host-on-teensy-4-1-doesn-t-receive-midi-from-EWI-5000-usb

midi monitor is therefore deprio

----

edit: another issue with FA-07 is that it sends dupe events. maybe an aggregate of multiple interfaces. anyway add a dupe checker for that.

last checkin addresses both issues.

Closed 2022-10-26.

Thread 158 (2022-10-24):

envelope: make params modulateable + curve support for A, D, R

thenfour, 2022-10-24:
we have optimized curve shaping code; we should allow shaping A,D,R curves.

and the whole thing kinda needs to be rewritten to support modulation. currently the effect doesn't take place until the next note-on.

Closed 2022-10-31.

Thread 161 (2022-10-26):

Refine concept of modulation polarity / support [-1,0] polarity

thenfour, 2022-10-26:
it's not intuitive what polarity does.
in addition, we want things like LFO to be able to work only in the negative pole, in order for example to have volume parameter = 0, modulated by LFO. Currently this would never allow silence. I guess you could hack it via a sidechain but it should be native.

----

it's actually already pretty logical and robust. Mod sources have a polarity type (envelopes are 0-1, LFOs are bipolar, etc). And modulation specs have a polarity treatment that lets you transform the source signal to something else. So you can then use an LFO as a positive 0-1 value for example. This is actually nice and i don't think should be changed.

But we can add a "default" or "natural" polarity treatment, which simply uses the existing source value and doesn't map it to anything. Might feel simpler to a user then that just wants an LFO to act as you'd expect, and only set this polarity treatment if needed.

Then, I also need to make sure things like volume parameters are clamped, otherwise there's no way to modulate volume with an LFO without it going negative and inverting a non-silent signal.

----

conclusion: adding the default polarity treatment is extremely simple, and i have tested that all this mapping already works great, i just needed to fix a problem in VolumeParam where negative values were being sign-flipped because of maths. That case is now handled and volume modulations work.

Closed 2022-10-28.

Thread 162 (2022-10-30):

modulation aux amount should be amount of attenuation, not a simple mul

thenfour, 2022-10-30:
case in point: envelope modulating a volume param, with aux velocity, aux range like 0.2.

The Aux range in this case means 0.2 is the maximum modulation ATTENUATION. Currently, it means the envelope will never peak above 0.2 value.

I'll document this in `modulation.md` but basically, in order to do this we need to move AWAY from

    y = base + (modval * modscale * auxval * auxscale)

to

    y = base + (modval * (modscale ± (auxValue * auxScale)))

where `±` is the opposite sign of `modscale`. It effectively does a lightly-optimized `lerp` based on auxvalue.

In order for this to work, aux polarity treatment must always map to positive values, and auxscale must always also be positive. It's more intuitive this way anwyay, never letting modscale grow.

Closed 2022-10-30.

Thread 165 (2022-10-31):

First note played per voice has some kind of volume ramp.

thenfour, 2022-10-31:
when max voices is 6, then the first 6 notes you play will have like a 100ms volume ramp. very annoying.

Hm this is caused by the filter node. When you change filter type, an instant change happens that can cause a click or boom; the ramp is necessary when switching filter types. And because of layers / loopstation / harmonizer, it's not known which filter type to initialize to.

The boom is real btw; i cannot just ignore the ramp in any case. It may be than at acceptable compromise is a small (20ms) ramp which would be heard only when a voice changes patch/filtertype/whatever. Not a *rare* case, but maybe rare enough and low enough impact that it's OK.

Because there's no other obvious solution. What *should* happen? Voices are allocated and must be able to switch filter types on the fly. The only solution is to make the filters not pop, which is kinda what the ramp does. Maybe finding a different method of ramping, for example a sort of smoothing of filter coefficients. But meh.

For now the ramp will just be reduced to a small value.

Closed 2022-10-31.

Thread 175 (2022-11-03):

LFO: better waveforms

thenfour, 2022-11-03:
Currently we just use the built-in teensy audio oscillator. It's a fine oscillator, but for LFO i want waveforms which are more tailored for the purpose.

For example a square wave for LFO *must* have some kind of smoothing. The immediate jumps are not really acceptable for LFOs. And they should not be band-limited but rather just smoothed. Ideally in a continuously adjustable way.

Implication: there needs to be a waveshape parameter.

* Sine-Triangle (smoothness, pulse width)
* Triangle-Saw (smoothness, pulse width)
* Sine-Square (smoothness, pulse width)
* Random (smoothness, density)

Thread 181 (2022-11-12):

make DC filter a performance / post fx feature; not a voice feature

thenfour, 2022-11-12:
currently DC filter is mixed with the Filter node, per-voice. makes little sense; it should go at the very end of the fx chain and specified in performance settings

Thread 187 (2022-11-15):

support ring modulation

thenfour, 2022-11-15:
worth a try; hard sync has led to some pretty wacky and usable sounds so might as well throw this in; it's very close.

this will be part of #182, giving oscillators access to each others' buffers

Closed 2022-11-15.

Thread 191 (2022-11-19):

ring mod and phase mod should probably be similarly-configured

thenfour, 2022-11-19:
ring mod and FM are both an oscillator-to-oscillator modulations and can be composed of a matrix of values. Some thought should be put into whether their menus should therefore look similar. Does ringmod benefit from chaining & feedback, for example?

Closed 2022-11-20.

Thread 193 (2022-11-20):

FM breakup sounds bad

thenfour, 2022-11-20:
when you push FM too far in FM8, the sound breaks up and eventually into almost white noise. Similar happens on clarinoid, but the transition from consonance to noise is not pretty at all and just sounds like you're mixing in noise gradually.

I suspect it's related both to the quality of waveforms, and the method of computation. Phase mgmt is probably necessary to keep the waveform stable and clean (see FM8's waveforms).

----

note that this little reaper JS demonstrates correct fm feedback, and it's what I believe I'm doing in clarinoid. this blends in 2 samples back as well, to help smooth breakup. A blend of about 50% of N-2 is the most stable.

```

slider1:0<0,1>fb amt
slider2:0<0,1>2nd sample

in_pin:left input
in_pin:right input
out_pin:left output
out_pin:right output

@init

dt = 940.0 / 44100.0;
a = 0.0;
fbN1 = 0.0;
fbN2 = 0.0;
fbN3 = 0.0;
@sample

a = a + dt;

spl0 =sin(a + (fbN1 + fbN2*slider2) * 10 * slider1);

spl0 = spl0 * 0.25;
spl1 = spl0;
fbN3 = fbN2;
fbN2 = fbN1;
fbN1 = spl0;

```
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

-----

update: with identical code, double-precision, the issue still exists. Actually the teensy waveform looks OK using an internal oscilloscope. #192 reveals that external oscilloscopes won't be reliable. Especially regarding feedback calculations, the internal calculations should all work fine.

This is tested with an isolated code example, sending audio data directly to the dac, not bommanoid application.

* The initial feedback range sounds good; i am fine with this. i hear the grainy texture coming in, it's what i expect to hear
* The initial breakup should have very high harmonics coming in. What I hear is some high harmonics but along with a lot of noise and a sort of digital instability.
* High param range should still be a stable, but coarse, waveform. On the teensy it's pretty much chaos. White noise and digitally oscillating glitches. There are even param values which seem to momentarily shift octaves etc.

What I can say is that the principle is correct, but there's something deeper to fix. It may be how floating point is handled on the CPU itself. I don't think it's related to the 16-bit processing stage, because all this should be confined to the float calculation.

I could do waveform diffs or something but what would I get out of that? I guess I could narrow the error down to a single initial operation that causes the breakdown. Would I be able to attribute that to the issue? How would I even approach fixing it? It's not like I'm going to start using a different floating point library or something. Maybe some ARM-specific flags or modes which affect floating point calculations in certain ranges? Or related to denormalized values?

-----

update: comparing identical code against x86, which looks and sounds as I expect, I see discrepancies. Tracking every calculation involved, the biggest culprits are multiplication & `std::sin`, but single operations in the worst case have 0.0001 (1E-4) error. That's kinda more than I would expect, but also within reasonable range for worst-case, especially when a trig operation is involved. I can see from tabular output that the feedback causes these errors to blow up.

Nothing related to denormalization, but just lots of accumulating tiny errors.

So even if there is a fix, it's mostly a matter of luck that it would affect the behavior in a better way. It's a shame that the actual behavior is so chaotic though. Maybe there's a way to force the chaos out, like resetting the feedback every wave cycle.

-----

update: resetting feedback every cycle seems to be more stable, but the issue is that cycles don't start on even sample boundaries, so the wave cycles are still not consistent. And that's a bit the issue: there would be no way to stabilize this unless cycles are on even sample boundaries, otherwise calculations will always diverge.

Aggressive oversampling might be a step in the right direction but it's also getting hacky.

Another idea is to do this in fixed-point 32-bit, where calculations may somehow be more stable?

thenfour, 2022-11-22:
with the issue mostly understood, "under control", and no additional actions to be taken, closing.

thenfour, 2022-11-23:
reopening because I have something.

The built-in audio lib now has bandlimited waveforms, and are all via 32-bit fixed-point calculations. Some experimenting shows that this indeed results in more stable feedback and FM behavior. So it's what i was converging on anyway but was afraid it was too much work for an experiment. Well it works, and I'll be adapting this oscillator class to suit my needs. Bonus: it's probably much more performant.

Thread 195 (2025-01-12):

Init screen should probably be a diagnostic screen

thenfour, 2025-01-12:
Something to make certain everything is ready to go.

* the current note (C4 for example)
* key states / anomalies
* pitch bend status

thenfour, 2025-01-19:
i have addressed this in slightly different ways:

- the key state screen is 1 button click away (no need to change the home screen then)
- current note and other data is already on the HUD
- more accurate and useful display of key states, and improved performance so it can be displayed without disrupting playback or perf
- pitch bend is displayed on an overlay

Closed 2025-01-19.

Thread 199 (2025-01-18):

encoder erratic

thenfour, 2025-01-18:
could be a matter of debouncing, or polling too infrequently? would be nice to fix this, or as an alternative have up/down pushbuttons.

note: it's updated from `MusicalState` via `mControlMapper->TaskRun();`. probably better to poll it more often in a separate task because encoders are so finnicky.

Closed 2025-01-18.

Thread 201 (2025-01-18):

latching octaves

thenfour, 2025-01-18:
#39 <-- reviving an old idea

very simple to implement considering we already keep current octave for LED indicator.

but it's not a magic bullet: when removing your finger it's pretty likely youll touch other keys accidentally.

Closed 2025-01-18.

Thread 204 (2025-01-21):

heuristic scale detector: refinement

thenfour, 2025-01-21:
recently added a heuristic-based scale detection algo. incoming notes build a "notes in context" heatmap, which is passed through a fit function to find the best-fitting scale.

this actually works well, but there are some variables which need tweaking:

1. context heat map pitch class attack time
2. ... release time
3. which scales are considered candidates
4. non-diatonic-note penalty
5. breath weighting (more breath = more weight)

These can be tweaked but should be done so using a local method, not constant guess-and-test tweaking on the device itself.

Further, I believe there needs to be careful thought about which scales are to be considered given a context. Some thoughts for consideration:

* Scale transitions: It's more likely to transition from Cmaj to Fmaj than from Bmaj to Fmaj
* Overlapping scales: it would be nice to find a way in which Cmaj pentatonic is a possibility as well as Cmaj. Basically if you're playing a B, C maj pentatonic is no longer an option. Non-diatonic penalty should cover this maybe? should be tested as a use-case.
* Overall scale likeliness. If you only play D-E-F over and over, are you most likely playing: C maj, F maj, D harmonic minor, or E hw diminished? All should theoretically be possible, but some are more likely than others. Several ideas are in the works to deal with this...
* Scale "character notes". Intuitively as a musician DEF suggests F maj or C maj; they're safe options because maj is more common than the others. To be considered harmonic minor it's important to have the C# present. And for a diminished scale it's important to have the first 2 notes, plus the nat 6th (like C, C#, A). But that still can suggest F# blues if that's an option. In that case to differentiate, the B or Bb is key. If B is present, definitely F# blues. If Bb is present, go with C dim. But if none are present go with blues because it's more common than diminished. Shall we implement weights for scale degrees and their importance to distinguish from other scales?

thenfour, 2025-01-22:
hm this has now all been implemented and should just need some tweaking to values to balance

Closed 2025-01-22.

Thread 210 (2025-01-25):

breath configuration needs more detail

thenfour, 2025-01-25:
there are rare occasions when breath min is too low and you get a continuous note.

* currently breath min is shown with 2 decimal places which is probably not sufficient
* the min can probably just be brought up from 0.10. 0.11 was feeling just fine.
* consider a kind of auto-calib simialr to mpr121 soft reset. it would assume you're not playing, and if the current breath val is greater than breath.min, the set it; with some margin.

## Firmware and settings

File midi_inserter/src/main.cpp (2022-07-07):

#include <Arduino.h>
#include <algorithm>
#include <MIDI.h>
#include <Bounce.h>
#include <cmath>
#include <WS2812Serial.h>

// setting analog resolution causes other problems and ugliness. don't.
// see https://www.pjrc.com/teensy/td_pulse.html
// on how to balance these values.
constexpr float gLEDPWMFrequency = 36621.09f;
constexpr int gLEDPWMResolution = 12;

constexpr int gLEDPWMMaxValue = (1 << gLEDPWMResolution) - 1;

constexpr int gFrameRate = 125;

#include "midibus.hpp"
#include "gui.hpp"
#include "misc.hpp"

// command: 0x10: set orange level (0-255)
// command: 0x11: set blue level (0-255)
// command: 0x20+N: set led N color (0-255 R, 0-255 G, 0-255 B)
constexpr byte gMIDICommandSetOrange = 0x10;
constexpr byte gMIDICommandSetBlue = 0x11;
constexpr byte gMIDICommandSetNRGB = 0x20;
constexpr byte gMIDICommandSetNRGBCount = 8;
constexpr byte gMIDICommandSimulateError = 0x30;
constexpr byte gMIDICommandBeatTrigger = 0x40;

clarinoid::Stopwatch gNoteOffTimer; // when a noteon happens, set a timer to send note off.
bool gWaitingForNoteOff = false;
static constexpr int gNoteOffDelayMS = 50;

constexpr int gGoNote = 14;

BigButtonReader gBigButton{16, 30, 200};

MidiPerformerGui gGui;

void ErrorCallbackA(int8_t n);
void ErrorCallbackB(int8_t n);

MidiBus gMidiBusA(Serial1, ErrorCallbackA);
MidiBus gMidiBusB(Serial2, ErrorCallbackB);

void ErrorCallbackA(int8_t n)
{
    gMidiBusA.ResetBus();
}

void ErrorCallbackB(int8_t n)
{
    gMidiBusB.ResetBus();
}

void setup()
{
    Serial.begin(9600);
    // delay(250);
    // while (!Serial);
    // Serial.println("beginning.");
}

// in order to not conflict with the other device's own identification message.
bool waitingForIdentify = false;
constexpr int identifyWaitMS = 500;
clarinoid::Stopwatch identifyTimer;

// assumes there's a sysex message in the hopper
void HandleIdentify(MidiBus &midiBus, const byte *sysexData, const int sysexLen)
{
    if (IsArrayEqual(sysexLen, sysexData, gMIDIIdentifyRequest))
    {
        gGui.SetIdentifyState(IdentifyState::Requested);
        identifyTimer.Restart();
        waitingForIdentify = true;
    }
}

// assumes there's a sysex message in the hopper
void HandleLEDCommand(MidiBus &midiBus, const byte *sysexData, int sysexLen)
{
    if (!ArrayBeginsWith(sysexLen, sysexData, gMIDICommandPrefix))
    {
        return;
    }

    // advance past the prefix
    sysexData += SizeofStaticArray(gMIDICommandPrefix);
    sysexLen -= SizeofStaticArray(gMIDICommandPrefix);

    while (true)
    {
        if (sysexLen < 1)
        {
            break; // EOF
        }
        else if (sysexData[0] == 0xf7)
        {
            break; // normal end of msg. though this is not part of the array so should actually never happen.
        }

        if (sysexData[0] == gMIDICommandBeatTrigger)
        {
            sysexData++; // advance past command byte
            sysexLen--;
            gGui.OnBeatTrigger();
            continue;
        }

        if (sysexData[0] == gMIDICommandSetOrange)
        {
            sysexData++; // advance past command byte
            sysexLen--;
            if (sysexLen < 1)
            {
                gGui.OnError();
                // Serial.println("Error: sysex data ended in the middle of LEDORANGE command.");
                break;
            }
            // read level
            byte level = sysexData[0];
            sysexData++; // advance past level byte
            sysexLen--;
            gGui.OnSetOrangeLevel(float(level) / 127);
            continue;
        }

        if (sysexData[0] == gMIDICommandSetBlue)
        {
            sysexData++; // advance past command byte
            sysexLen--;
            if (sysexLen < 1)
            {
                // Serial.println("Error: sysex data ended in the middle of BLUE command.");
                break;
            }
            // read level
            byte level = sysexData[0];
            sysexData++; // advance past level byte
            sysexLen--;
            gGui.OnSetBlueLevel(float(level) / 127);
            continue;
        }
        else if (sysexData[0] == gMIDICommandSimulateError)
        {
            gGui.OnError();
            break; // malformed.
        }
        else
        {
            if (sysexLen < 4)
            {
                gGui.OnError();
                break; // malformed.
            }

            int nled = sysexData[0];
            nled -= gMIDICommandSetNRGB;

            if (nled >= gMIDICommandSetNRGBCount)
            {
                gGui.OnError();
                break;
            }

            gGui.SetLedStripColor(
                nled, Color{float(sysexData[1]) / 127, float(sysexData[2]) / 127, float(sysexData[3]) / 127});

            sysexData += 4;
            sysexLen -= 4;
            continue;
        }
        break; // if you get here nothing was processed therefore we don't understand the commend therefore cursor
               // not
               // advancing therefore endless loop therefore omg just stop
    }
}

// return true if there's any activity
bool ProcessMIDIBusActivity(MidiBus &bus)
{
    if (!bus.mMIDI.read())
        return false;

    if (bus.mMIDI.getType() != midi::SystemExclusive)
        return true;
    const byte *sysexData = bus.mMIDI.getSysExArray();
    const int sysexLen = bus.mMIDI.getSysExArrayLength();
    HandleIdentify(bus, sysexData, sysexLen);
    HandleLEDCommand(bus, sysexData, sysexLen);
    return true;
}

void loop()
{
    bool activityA = false;
    bool activityB = false;
    do
    {
        // READ MIDI A
        activityA = ProcessMIDIBusActivity(gMidiBusA);
        if (activityA)
        {
            gGui.OnMidiARXTX();
        }
        activityB = ProcessMIDIBusActivity(gMidiBusB);
        if (activityB)
        {
            gGui.OnMidiBRXTX();
        }
    } while (activityA || activityB);

    if (waitingForIdentify)
    {
        if (identifyTimer.ElapsedTime().ElapsedMillisI() >= identifyWaitMS)
        {
            waitingForIdentify = false;
            gMidiBusA.mMIDI.sendSysEx(SizeofStaticArray(gMIDIIdentifyResponse), gMIDIIdentifyResponse, true);
            gMidiBusB.mMIDI.sendSysEx(SizeofStaticArray(gMIDIIdentifyResponse), gMIDIIdentifyResponse, true);
            gGui.SetIdentifyState(IdentifyState::Sent);
            gGui.OnMidiABTX();
        }
    }

    // HANDLE BIG BUTTON NOTE INSERTION & SUBSEQUENT NOTE-OFF
    if (gBigButton.DidTrigger())
    {
        gGui.OnBigButtonSendNoteViaBusB();
        gMidiBusB.mMIDI.sendNoteOn(gGoNote, 126, 1);
        gNoteOffTimer.Restart();
        gWaitingForNoteOff = true;
    }
    if (gWaitingForNoteOff && gNoteOffTimer.ElapsedTime().ElapsedMillisI() >= gNoteOffDelayMS)
    {
        gMidiBusB.mMIDI.sendNoteOff(gGoNote, 0, 1);
        gGui.OnMidiBTX();
        gWaitingForNoteOff = false;
    }

    gGui.OnFrame();

    delayMicroseconds(100);
}

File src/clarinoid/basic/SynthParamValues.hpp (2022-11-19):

#pragma once

namespace clarinoid
{

template <typename T, std::enable_if_t<std::is_integral<T>::value, int> = 0>
struct IntParam
{
    T mValue;

    T GetValue() const
    {
        return mValue;
    }
    void SetValue(T v)
    {
        mValue = v;
    }

    explicit IntParam(T defaultValue) : mValue(defaultValue)
    {
    }
    // IntParam(const IntParam<T> &rhs) = default;
    // IntParam<T> &operator=(const IntParam<T> &rhs) = default;

    // Result SerializableObject_ToJSON(JsonVariant rhs) const
    // {
    //     return {rhs.set(mValue)};
    // }

    // Result SerializableObject_Deserialize(JsonVariant obj)
    // {
    //     if (!obj.is<T>())
    //         return Result::Failure("expected integer");
    //     mValue = obj.as<T>();
    //     return Result::Success();
    // }
};

template <typename T, std::enable_if_t<std::is_integral<T>::value, int> = 0>
Result Serialize(JsonVariantWriter &myval, IntParam<T> &param)
{
    return myval.WriteNumberValue(param.mValue);
}

template <typename T, std::enable_if_t<std::is_integral<T>::value, int> = 0>
Result Deserialize(JsonVariantReader &myval, IntParam<T> &param)
{
    if (myval.mType != JsonDataType::Number)
    {
        return Result::Failure("expected number");
    }
    param.mValue = myval.mNumericValue.Get<T>();
    return Result::Success();
}

static constexpr size_t arcih = sizeof(IntParam<int>);

// serializing floats is fun. on one hand, using the decimal representation is terrible,
// on the other hand i want it to be human-readable.
struct FloatParam
{
    using T = float;
    T mValue;

    T GetValue() const
    {
        return mValue;
    }
    void SetValue(T v)
    {
        mValue = v;
    }

    explicit FloatParam(float defaultValue) : mValue(defaultValue)
    {
    }
    FloatParam(const FloatParam &rhs) = default;
    FloatParam &operator=(const FloatParam &rhs) = default;

    // Result SerializableObject_ToJSON(JsonVariant rhs) const
    // {
    //     return {rhs.set(mValue)};
    // }

    // Result SerializableObject_Deserialize(JsonVariant obj)
    // {
    //     Result ret = Result::Success();
    //     if (!ret.Requires(obj.is<T>(), "expected float"))
    //         return ret;
    //     mValue = obj.as<T>();
    //     return ret;
    // }
};

Result Serialize(JsonVariantWriter &myval, FloatParam &param)
{
    return myval.WriteNumberValue(param.mValue);
}

Result Deserialize(JsonVariantReader &myval, FloatParam &param)
{
    if (myval.mType != JsonDataType::Number)
    {
        return Result::Failure("expected number");
    }
    param.mValue = myval.mNumericValue.Get<float>();
    return Result::Success();
}

// serializing floats is fun. on one hand, using the decimal representation is terrible,
// on the other hand i want it to be human-readable.
struct BoolParam //: ParameterBase
{
    using T = bool;
    T mValue = false; // making public, in case you need a reference. (see GuiPerformanceApp.hpp)

    T GetValue() const
    {
        return mValue;
    }
    void SetValue(T v)
    {
        mValue = v;
    }

    BoolParam() = default;

    explicit BoolParam(bool initialValue) : mValue(initialValue)
    {
    }

    // Result SerializableObject_ToJSON(JsonVariant rhs) const
    // {
    //     return {rhs.set(mValue ? 1 : 0)};
    // }

    // Result SerializableObject_Deserialize(JsonVariant obj)
    // {
    //     if (!obj.is<int>())
    //         return Result::Failure("expected 1 or 0");
    //     int t = obj.as<int>();
    //     mValue = (t != 0);
    //     return Result::Success();
    // }
};

Result Serialize(JsonVariantWriter &myval, BoolParam &param)
{
    return myval.WriteNumberValue(param.mValue ? 1 : 0);
}

Result Deserialize(JsonVariantReader &myval, BoolParam &param)
{
    if (myval.mType == JsonDataType::Boolean)
    {
        param.mValue = myval.mBooleanValue;
        return Result::Success();
    }
    if (myval.mType == JsonDataType::Number)
    {
        param.mValue = (myval.mNumericValue.Get<int>() == 1);
        return Result::Success();
    }
    return Result::Failure("expected boolean");
}
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

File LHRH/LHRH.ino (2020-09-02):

// Teensy LC
// 48mhz
// speed-optimizing for some reason causes problems i don't know why.
// so choose smallest code

#define LH
//#define RH

//============================================================

uint32_t gFrameNumber = 0;

#include "Shared_CCTxRx.h"
#include "Shared_CCSwitch.h"
#include "Shared_CCLeds.h"

static int gFocusedKeyIndex = -1;

int gFocusedKeyData = -1; // which key set the following data...
uint32_t gFocusedTouchReadMicros;
uint32_t gFocusedTouchReadValue;
uint32_t gFocusedTouchReadUntouchedMicros;
uint32_t gFocusedTouchReadThresholdMicros;

#include "CCTouchKey.h"
#include "CCPressure.h"

// common
CCLeds leds(10, 2,
#ifdef LH
  false /* reversed */
#else // RH
  true /* reversed */
#endif // LH/RH
  );

#ifdef LH
CCTouchKey key1(15, KEY_LHX1);
CCTouchKey key2(16, KEY_LH1);
CCTouchKey key3(17, KEY_LH2);
CCTouchKey key4(18, KEY_LH3);
CCTouchKey key5(19, KEY_LH4);
CCTouchKey key6(22, KEY_LHX2);

CCBreathSensor wind(A0);
CCBiteSensor bite(A6);
CCOnOffSwitch backButton(6, 5);
CCTouchKey octave1(0, KEY_O1);
CCTouchKey octave2(1, KEY_O2);
CCTouchKey octave3(3, KEY_O3);
CCTouchKey octave4(4, KEY_O4);
#else // RH
CCTouchKey key1(22, KEY_RHX1);
CCTouchKey key2(15, KEY_RH1);
CCTouchKey key3(16, KEY_RH2);
CCTouchKey key4(17, KEY_RH3);
CCTouchKey key5(18, KEY_RH4);
CCTouchKey key6(19, KEY_RHX2);
CCPitchStripSensor pitchDown(A0);
CCOnOffSwitch oooButton1(11, 5);
CCOnOffSwitch oooButton2(12, 5);
#endif // LH/RH

CCThrottler ledThrottle(20);

CCLHRHTxRx gTxRx(Serial2);
LHRHPayload gPayload;
//bool gDirty = false;
TransientActivityLED gTXIndicator(250, 250);
TransientActivityLED gRXIndicator(250, 250);

LHRHLEDMode gLEDMode = LHRHLEDMode::Debug;

// this cannot be a templated function, because you cannot bind bitfields like that.
inline void CaptureButton(CCTouchKey& key, CapTouchKeyData& dest)
{
  // TODO: if you want to get more detailed data, we should implement some way to debug-focus a key
  // so we can capture in more real-time.
  dest.IsPressed = key.IsPressed();
  //dest.touchReadMicros = key.GetTouchReadMicros();
  //dest.maxTouchReadMicros = key.GetTouchReadMaxMicros();
}

void setup() {
  Serial.begin(9600);

  pinMode(13, OUTPUT);
  SetupUpdateObjects();
}

void loop() {
  gFocusedKeyData = -1;
  gFrameNumber ++;
  UpdateUpdateObjects();

  if (gTxRx.mHaveNewData) {
    gRXIndicator.Touch();
    gLEDMode = gTxRx.mReceivedData.data.ledMode;
    gFocusedKeyIndex = gTxRx.mReceivedData.data.focusedTouchKey;
    switch(gTxRx.mReceivedData.data.cmd) {
    case CommandFromMain::None:
      break;
    case CommandFromMain::EnableOrangeLED:
      digitalWrite(13, HIGH);
      break;
    case CommandFromMain::DisableOrangeLED:
      digitalWrite(13, LOW);
      break;
    case CommandFromMain::ResetTouchKeys:
      gTouchKeyCalibrator.ResetAllKeys();
      break;
    case CommandFromMain::SetTouchMaxFactor:
      gTouchKeyCalibrator.SetMaxFactorOfAllKeys(gTxRx.mReceivedData.data.cmdFloatParam1);
      break;
    }
  }

  if (gFocusedKeyIndex >= 0 && gFocusedKeyIndex < (int)SizeofStaticArray(gKeyDesc)) {
#ifdef LH
    if (gKeyDesc[gFocusedKeyIndex].mLH) {
#else // RH
    if (!gKeyDesc[gFocusedKeyIndex].mLH) {
#endif // LHRH
      if (gFocusedKeyData == gFocusedKeyIndex) {
        gPayload.data.focusedKey = gFocusedKeyData;
        gPayload.data.focusedTouchReadMicros = gFocusedTouchReadMicros;
        gPayload.data.focusedTouchReadValue = gFocusedTouchReadValue;
        gPayload.data.focusedTouchReadUntouchedMicros = gFocusedTouchReadUntouchedMicros;
        gPayload.data.focusedTouchReadThresholdMicros = gFocusedTouchReadThresholdMicros;
      }
    }
  }

  // construct the payload & check if dirty / needs to be sent.
  // only unset "dirty" if we actually send the packet.
  CaptureButton(key1, gPayload.data.keys[0]);
  CaptureButton(key2, gPayload.data.keys[1]);
  CaptureButton(key3, gPayload.data.keys[2]);
  CaptureButton(key4, gPayload.data.keys[3]);
  CaptureButton(key5, gPayload.data.keys[4]);
  CaptureButton(key6, gPayload.data.keys[5]);
#ifdef LH
//  gDirty = true;
  gPayload.data.pressure1 = wind.GetRawValue();
  gPayload.data.pressure2 = bite.GetRawValue();

  gPayload.data.button1 = backButton.IsCurrentlyPressed();
  CaptureButton(octave1, gPayload.data.octaveKeys[0]);
  CaptureButton(octave2, gPayload.data.octaveKeys[1]);
  CaptureButton(octave3, gPayload.data.octaveKeys[2]);
  CaptureButton(octave4, gPayload.data.octaveKeys[3]);
#else // RH
//  gDirty = true;
  gPayload.data.pressure1 = pitchDown.GetRawValue();

  gPayload.data.button1 = oooButton1.IsCurrentlyPressed();
  gPayload.data.button2 = oooButton2.IsCurrentlyPressed();
#endif // LH/RH



  gTxRx.Send(gPayload);
  gTXIndicator.Touch();

  if (ledThrottle.IsReady())
  {
    switch (gLEDMode) {
    case LHRHLEDMode::Off:
      for (int i = 0; i < 10; ++ i) {
        leds.setPixelColor(i, 0, 0, 0);
      }
      break;
    case LHRHLEDMode::Minimal:
      leds.setPixelColor(0, col(gTXIndicator.GetState()), col(gRXIndicator.GetState()), col(gRXIndicator.GetState()));
      break;
    case LHRHLEDMode::MainControlled:
    {
      auto& d = gTxRx.mReceivedData.data;
      for (int i = 0; i < 10; ++ i) {
        leds.setPixelColor(i, d.leds[i][0], d.leds[i][1], d.leds[i][2]);
      }
      break;
    }
    case LHRHLEDMode::Debug:
#ifdef LH
      leds.setPixelColor(0, col(gTXIndicator.GetState()), col(gRXIndicator.GetState()), col(gRXIndicator.GetState()));
      // 1 = off
      leds.setPixelColor(2, 0, col(bite.Value01Estimate()), 0);
      leds.setPixelColor(3, 0, col(wind.Value01Estimate()), 0);
      leds.setPixelColor(4, 0, 0, col(key1.IsPressed()));
      leds.setPixelColor(5, 0, 0, col(key2.IsPressed()));
      leds.setPixelColor(6, 0, col(octave4.IsPressed()), col(key3.IsPressed()));
      leds.setPixelColor(7, 0, col(octave3.IsPressed()), col(key4.IsPressed()));
      leds.setPixelColor(8, 0, col(octave2.IsPressed()), col(key5.IsPressed()));
      leds.setPixelColor(9, col(backButton.IsCurrentlyPressed()), col(octave1.IsPressed()), col(key6.IsPressed()));
#else // RH
      leds.setPixelColor(0, col(gTXIndicator.GetState()), col(gRXIndicator.GetState()), col(gRXIndicator.GetState()));
      // 1 = off
      // 2 = off
      leds.setPixelColor(3, 0, col(pitchDown.Value01Estimate()), 0);
      leds.setPixelColor(4, 0, 0, col(key1.IsPressed()));
      leds.setPixelColor(5, 0, 0, col(key2.IsPressed()));
      leds.setPixelColor(6, 0, 0, col(key3.IsPressed()));
      leds.setPixelColor(7, 0, 0, col(key4.IsPressed()));
      leds.setPixelColor(8, 0, col(oooButton1.IsCurrentlyPressed()), col(key5.IsPressed()));
      leds.setPixelColor(9, 0, col(oooButton2.IsCurrentlyPressed()), col(key6.IsPressed()));
#endif // LH/RH
      break;
    }
    leds.show();
  }
}

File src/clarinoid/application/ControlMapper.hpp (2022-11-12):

#pragma once

#include "ControlSource.hpp"
#include "FunctionHandler.hpp"
#include <clarinoid/basic/Basic.hpp>
#include <clarinoid/settings/AppSettings.hpp>

namespace clarinoid
{

struct SynthPresetAMappableFunction : FunctionHandler
{
    IInputSource *mInputSrc;
    AppSettings *mAppSettings;

    void Init(AppSettings *appSettings, IInputSource *psrc)
    {
        mInputSrc = psrc;
        mAppSettings = appSettings;
    }

    virtual void FunctionHandler_Update(const ControlValue &v) override
    {
        int nv = v.AsRoundedInt();
        nv = RotateIntoRange(nv, SYNTH_PRESET_COUNT);
        int old = mAppSettings->GetCurrentPerformancePatch().mSynthPatchA.GetValue();
        if (old != nv)
        {
            auto &p = mAppSettings->FindSynthPreset(nv);
            mInputSrc->InputSource_ShowToast(String("Synth patch A: ") + nv + " (" + (nv - old) + ")\r\n" + p.mName.GetValue());
            mAppSettings->GetCurrentPerformancePatch().mSynthPatchA.SetValue(nv);
        }
    }
    virtual ControlValue FunctionHandler_GetCurrentValue() const override
    {
        int v = mAppSettings->GetCurrentPerformancePatch().mSynthPatchA.GetValue();
        return ControlValue::IntValue(v);
    }
};

struct SynthPresetBMappableFunction : FunctionHandler
{
    IInputSource *mInputSrc = nullptr;
    AppSettings *mAppSettings = nullptr;

    void Init(AppSettings *appSettings, IInputSource *psrc)
    {
        CCASSERT(!!psrc);
        CCASSERT(!!appSettings);
        mInputSrc = psrc;
        mAppSettings = appSettings;
    }

    virtual void FunctionHandler_Update(const ControlValue &v) override
    {
        CCASSERT(!!mAppSettings);
        int nv = v.AsRoundedInt();
        if (nv < -1)
        {
            nv = SYNTH_PRESET_COUNT - 1;
        }
        if (nv >= (int)SYNTH_PRESET_COUNT)
        {
            nv = -1;
        }
        int old = mAppSettings->GetCurrentPerformancePatch().mSynthPatchB.GetValue();
        if (old != nv)
        {
            // auto &p = mAppSettings->FindSynthPreset(nv);
            auto name = mAppSettings->GetSynthPatchName(nv);
            mInputSrc->InputSource_ShowToast(String("Synth patch B: ") + nv + " (" + (nv - old) + ")\r\n" + name);
            mAppSettings->GetCurrentPerformancePatch().mSynthPatchB.SetValue(nv);
        }
    }
    virtual ControlValue FunctionHandler_GetCurrentValue() const override
    {
        int v = mAppSettings->GetCurrentPerformancePatch().mSynthPatchB.GetValue();
        return ControlValue::IntValue(v);
    }
};

struct HarmPresetMappableFunction : FunctionHandler
{
    IInputSource *mInputSrc;
    AppSettings *mAppSettings;

    void Init(AppSettings *appSettings, IInputSource *psrc)
    {
        mInputSrc = psrc;
        mAppSettings = appSettings;
    }

    virtual void FunctionHandler_Update(const ControlValue &v) override
    {
        int nv = v.AsRoundedInt();
        nv = RotateIntoRange(nv, HARM_PRESET_COUNT);
        int old = mAppSettings->GetCurrentPerformancePatch().mHarmPreset.GetValue();
        if (old != nv)
        {
            auto &p = mAppSettings->FindHarmPreset(nv);
            mInputSrc->InputSource_ShowToast(String("Harmonizer: ") + nv + " (" + (nv - old) + ")\r\n" + p.mName.GetValue());
            mAppSettings->GetCurrentPerformancePatch().mHarmPreset.SetValue(nv);
        }
    }
    virtual ControlValue FunctionHandler_GetCurrentValue() const override
    {
        int v = mAppSettings->GetCurrentPerformancePatch().mHarmPreset.GetValue();
        return ControlValue::IntValue(v);
    }
};

struct PerfPresetMappableFunction : FunctionHandler
{
    IInputSource *mInputSrc = nullptr;
    AppSettings *mAppSettings = nullptr;

    void Init(AppSettings *appSettings, IInputSource *psrc)
    {
        CCASSERT(!!psrc);
        CCASSERT(!!appSettings);
        mInputSrc = psrc;
        mAppSettings = appSettings;
    }

    virtual void FunctionHandler_Update(const ControlValue &v) override
    {
        CCASSERT(!!mAppSettings); // make sure Init() is called!
        int nv = v.AsRoundedInt();
        nv = RotateIntoRange(nv, PERFORMANCE_PATCH_COUNT);
        int old = mAppSettings->mCurrentPerformancePatch.GetValue();
        if (old != nv)
        {
            auto name = mAppSettings->GetPerfPatchName(nv);
            mInputSrc->InputSource_ShowToast(String("Perf: ") + nv + " (" + (nv - old) + ")\r\n" + name);
            mAppSettings->mCurrentPerformancePatch.SetValue(nv);
        }
    }
    virtual ControlValue FunctionHandler_GetCurrentValue() const override
    {
        int v = mAppSettings->mCurrentPerformancePatch.GetValue();
        v = RotateIntoRange(v, PERFORMANCE_PATCH_COUNT);
        return ControlValue::IntValue(v);
    }
};

struct TransposeMappableFunction : FunctionHandler
{
    IInputSource *mInputSrc;
    AppSettings *mAppSettings;

    void Init(AppSettings *appSettings, IInputSource *psrc)
    {
        mInputSrc = psrc;
        mAppSettings = appSettings;
    }

    virtual void FunctionHandler_Update(const ControlValue &v) override
    {
        int nv = v.AsRoundedInt();
        if (nv < -48)
        {
            mInputSrc->InputSource_ShowToast(String("Transposition\r\ntoo low"));
            return;
        }
        if (nv > 48)
        {
            mInputSrc->InputSource_ShowToast(String("Transposition\r\ntoo high"));
            return;
        }
        int old = mAppSettings->GetCurrentPerformancePatch().mTranspose.GetValue();
        if (old != nv)
        {
            mInputSrc->InputSource_ShowToast(String("Transpose: ") + nv + " (" + (nv - old) + ")");
            mAppSettings->GetCurrentPerformancePatch().mTranspose.SetValue(nv);
        }
    }
    virtual ControlValue FunctionHandler_GetCurrentValue() const override
    {
        return ControlValue::IntValue(mAppSettings->GetCurrentPerformancePatch().mTranspose.GetValue());
    }
};
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

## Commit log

2020-08-14 first crack at LHRH module
    [LHRH.ino]
2020-08-14 much work on Main, but tx/rx not working. committing before trying EasyTransfer
    [LHRH.ino, MAIN.ino]
2020-08-15 fixes #3 and #1 ok capacitive touching should be set.
    [LHRH.ino]
2020-08-16 fixed note on thresh, added midi activity light, fixed inaccurate midi message order sending
    [MAIN.ino]
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2020-08-18 more structure to menu app system, added uptime & notes played, more structure to encoder reading
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2020-08-24 reinit cap touch untouched now uses a moving average to avoid transients, fixed touchRead round robin behavior, now transmitting cap touch debug info, led brightness and led mode foundation laid, fix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
    [CCMenuDebug.h, LHRH.ino, MAIN.ino]
2020-08-25 smarter stagger grouping, tweaks to cap touch calib, added key reset trigger, support for trigger setting items, fixed mHaveNewData initialization, more accurate CCThrottlerT timing, metronome screen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
    [CCMenuDebug.h, LHRH.ino, MAIN.ino]
2020-08-27 mega commit: enum settings and tons of other
    - support for text margin
    - modal render
    - Die() / CCASSERT() etc for better debugging
    - enum info support
    - better settings list initialization
    - list control
    - lots of cleanup & rearrange
    - enum setting item and editor
    - property binding code
    - harmonizer settings app WIP
    [CCMenuDebug.h, MAIN.ino]
2020-08-28 added profiling, fixed checker pattern in plots, added throttling to pot readings, cleanup
    [CCMenuDebug.h, MAIN.ino]
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2020-09-02 fixed #6 pitch down sensor works. Fixes #18 removed periodic calibration of touch keys. Added pitch calibration to settings.
    [CCMenuDebug.h, LHRH.ino]
2020-09-05 fixes #19 - migrated to platform IO. what a breath of fresh air.
    [CCMenuDebug.h, main.cpp]
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2020-09-19 Mega refactor of project structure. Let's make this a little more organized. Also some minor changes...
    - throttle Tx from lhrh
    - throttle analog reads on lhrh
    - startup display msg
2020-09-19 removing ignored files, fixing pitch down and breath extents, breaking out looper files, fixing some musical voice state changes (looper works)
2020-09-20 added test clock, easier loop access, correct pitch loop serialization, better voice unassigning. still WIP major.
2020-09-20 refactor synth for unit tests, moving some teensy audio stuff back into the main graph
2020-09-22 added loopstation trigger modes, more insight in the menus for loopstation, increased to 384kb and put into DMA memory.
2020-09-22 harmonizer, looper bug fixes, holistic progress
    - put much of harmonizer in place except for interval selection
    - don't allow committing the last loop layer (so live voice can still always play)
    - dial back loop memory; it was causing OOM issuess
    - synth is now controlled by presets an not only hardcoded though it's very primitive and WIP.
    [HarmonizerSettings.hpp, Stopwatch.hpp]
2020-09-23 added detune, removed lhrh tx throttling, fixing typos, small tweaks.
    [SynthSettings.hpp]
2020-09-26 harmonizer works, improved error handling, multi setting items work, harm settings works,
    [HarmonizerSettings.hpp, SynthSettings.hpp]
2020-09-26 new pitch bend system with various regions seems to work more reliably
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2020-10-03 wip scale follower system end-to-end, but map generation not working yet.
    [Stopwatch.hpp]
2020-10-04 scale follower LUT generation seems reasonably solid using a distance metric. Fixed deduced harmonization for live voice.
    [HarmonizerSettings.hpp]
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2020-10-27 adding synth preset editing, oscillator tuning, incremental updates to scale follower LUT generation
    [SynthSettings.hpp]
2020-12-02 mega commit: bassoonoid, new taskman, new app structure... WIP though. audio not working.
    [BassoonoidMain.cpp, ControlMapper.hpp, HarmonizerSettings.hpp]
2020-12-06 mega commit, bassoonoid is working but still very much WIP
    - new task manager design with critical / normal classes. but it's not robust enough to handle very dense execution like we currently have so i plan to change it to some kind of static plan.
    - fixes in settings multi items
    - tests now work
    - added circular array
    - added performance monitoring menu app
    - added individual subitem timings for musical state
    - added NoInterrupts class
    - added breath calibration setting item
    - breath scaling now works better, also added curve
    - added multi label setting item
    - synth graph is now mono
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2020-12-13 fixes #45 all tests done, practical cases tested working.
    [ControlMapper.hpp, ControlMapping.hpp]
2020-12-21 adding breath calibration, color LED2, 2-octave key change, plotter simplification and ability to render to any viewport
2020-12-23 restoring synth settings app, adding fine & coarse editing, editable synth filt and sync ranges, master gain, fixing bug in settings list showing the focused item
    [ControlMapper.hpp, SynthSettings.hpp]
2020-12-23 synth menu UI enhancements. IsEnabled now always a Property<bool>. Adding pitch bend mapping. Adding read-only property support.
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2021-02-15 some progress on #49 LEDs now show note, scale follower, and randomness
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2021-02-21 LED tweaks, now showing Midi note & filter cutoff in menu, switched to a Biquad filter
2021-02-21 fixes #50 get midi working again
    [SynthSettings.hpp]
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2021-02-27 adding peak & hold LEDs, DC filter, fixing warnings,
    [SynthSettings.hpp]
2021-02-27 adding loopstation function mappings, new upper octave key behavior, more peak LED stuff,
2021-05-22 fixes #59, fixes #60: faster startup and slower bus speeds
    [BassoonoidMain.cpp]
2021-05-22 fixes #58 adding "hold pitch" feature
    [ControlMapper.hpp, ControlMapping.hpp]
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2021-05-22 fixing pitch hold toast, refining bassoonoid button mappings, adding quick preset permutations
    [SynthSettings.hpp]
2021-05-26 fixes #51 metronome works again, plus goodies. metronome was broken because we were treating milliseconds as microseconds so it was total chaos the metronome settings app was using old style code and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
    [ControlMapper.hpp, ControlMapping.hpp, Stopwatch.hpp]
2021-05-27 fixes #63 display apps scrolling into negative. tweaks to bassoonoid default settings.
    [SynthSettings.hpp]
2021-06-14 Tweaking clarinoid2 task timings, bus speeds, adding MPR121 data to debug display, increased filter range fixes #66
    [SynthSettings.hpp]
2021-06-14 fixes #67 breath mapping now corresponds to note on thresh. Removed note on thresh concept. Tweaked ranges. LED work. Fixed broken octave logic.
    [UnipolarCalibration.hpp]
2021-06-15 fixing adjusted key mappings, fixing wrong filter range settings
    [SynthSettings.hpp]
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2021-06-16 populating more default clarinoid2 presets int settings weren't able to adjust with encoder: fixed pitch finetune now can be negative runtime waveform types and pulse widths take effect immediately.
    [SynthSettings.hpp]
2021-06-19 clarinoid2 mpr121 tweaks, bassoonoid build fixing and preset refinements
    [BassoonoidMain.cpp, SynthSettings.hpp]
2021-06-20 Enabling harmonizer again, completing its settings app. Created multi numeric setting item, adding current synth preset to front page
2021-06-20 fixed: breath was not quiiite reaching 0.00 so note offs were not happening, messing with harm sequence. fixed: emit live note was not respected harmonizer menu has voice info
    [HarmonizerSettings.hpp]
2021-06-20 pitch bend range added to settings app pitch bend mapping design updates (pitchup + pitchdown), and using unipolar calib editor
2021-06-21 fixes #70: harmonizer voices can change pitch bend participation behavior.
    [HarmonizerSettings.hpp]
2021-06-21 fixes #69 can now copy harm & synth presets
    [HarmonizerSettings.hpp]
2021-06-22 Default pan now works, pan for harmonized voices now is correct.
    [SynthSettings.hpp]
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2021-06-27 fixing #73 buffer overrun causing crash in modulations adding names to modulation list adding pan flute & saw brass patches removing unused mod destinations
    [SynthSettings.hpp]
2021-06-27 Fixed: some voices not being silenced related to harmonizer Added "Fine" modifier indicator to Display Added HarmPatchOnOffToggle function More helpful clarinoid2 LED meter config fixed: LFO freq ran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
    [ControlMapper.hpp, ControlMapping.hpp, HarmonizerSettings.hpp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]
2021-06-30 forked & reworked polyblep oscillator so it's more maintanable; now we can make changes & improvements
    [HarmonizerSettings.hpp, clarinoid2Main.cpp]
2021-06-30 #74 janky attempt to control MPR121. at least soft reset works. tweaks to harmonizer settings
    [HarmonizerSettings.hpp]
2021-07-03 per-oscillator portamento setting preset tweaks & setting tweaks for clarinoid2 better metronome display for clarinoid2 peak & more aggressive LED for clarinoid2
    [SynthSettings.hpp]
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2021-07-05 kicad randomness initial checkin
    [clarinoid3.kicad_pcb, clarinoid3.sch]
2021-07-10 oscillators are a bit more organized; less copy/paste code
    [SynthSettings.hpp]
2021-07-10 fixes #80, fixes #75 oscillator phase & phase retrig can now be specified
    [SynthSettings.hpp]
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2021-07-10 fixes #78 oscillators have independent pan, and stereo spread control.
    [SynthSettings.hpp]
2021-07-13 added possibility of disabling oscillators & filters when not in use, but currently adds artifacts so not using it. default stereo width adding a better trumpet patch fixed broken harm patch display 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
    [SynthSettings.hpp]
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2021-07-18 fixes #101 pitch bend now per oscillator, increased range, and added "snap strength" which so far feels a bit useless but ok...
    [SynthSettings.hpp]
2021-07-19 fixes #104: adding performance patches which encapsulate master FX, adding a second selected synth patch as a doubling layer - adding support for modifier keys - remapping some controls for clarinoid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
    [ControlMapper.hpp, ControlMapping.hpp, HarmonizerSettings.hpp]
2021-07-21 WIP FM synthesis #84 - adding course modifier mapping for clarinoid2 - fixing synth patch settings app using wrong mapping - adding FMAlgo & FM Feedback, but they are not really working like one woul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
    [SynthSettings.hpp]
2021-07-21 #84 a couple more fm algos which can interact with the osc sync function fixing the synth patch editor which was still broken.
    [SynthSettings.hpp]
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2021-07-24 tweak pan flute map clarinoid2 enc button to font change fixed inverted text for custom fonts better display of modifiers fixes #107 adding remaining envelope params
    [SynthSettings.hpp, UnipolarCalibration.hpp]
2021-07-24 correcting glitchy env settings
    [SynthSettings.hpp]
2021-07-24 envelope fixes oops trumpet patch was boned
    [SynthSettings.hpp]
2021-07-25 - fixed : changing perf patch now updates BPM - adding sysinfo provider which should make a lot of info more accessible - adding a HUD (#102) - fixed: peak is now max of both L and R channels - fixed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
    [UnipolarCalibration.hpp]
2021-07-25 amending last commit: missing file and tweaks that i think were causing test device to crash
2021-07-28 font tester app crashes test device sometimes but it's no longer needed so disabling better abstraction for GuiApp stuff
2021-07-30 Fixed odd crashing in test device: display tasks running before 1st update task caused issues in the PerformanceApp
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2021-08-01 #96 doing some more filter profiling. hot spot is simply in the OnePoleFilter sample processor math. I have ideas.... test project builds again, fixing some build warnings
    [HarmonizerSettings.hpp, Stopwatch.hpp, SynthSettings.hpp]
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2021-08-01 using composite control for more things, restructuring Gui stuff a bit now that design is settling down gfx work on performance pages fixed bug in Property<T> for binding to references. I forgot abou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
    [BaseDefs.hpp]
2021-08-02 preparing for real gui performance app - bringing back eighties font - refining gui label ctor - adding correct props to performance settings
2021-08-02 BAD BUILD because clarinoid2 is currently only able to support 2 voices. - adding guiperf page to clarinoid2 - finished page1 of guiperf app - task manager now wraps all tasks in NoInterrupts, which 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
2021-08-02 MEGA commit with tons of nits and refactors. - IDisplay now makes way for creating a mock display which can be used for testing / profiling. - nointerrupts wrapping around most tasks. during debuggin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
    [BaseDefs.hpp, ControlMapper.hpp, ControlMapping.hpp]
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2021-08-06 - using some more fast math functions - small fixes - knob snaps to 0.25 values - knob snaps to min range value - knob is more tolerant to rounding errors
    [SynthSettings.hpp]
2021-08-07 UNTESTED #116 major rework of modulation source & destination plumbing. source & dest can both be either K-Rate or A-Rate #96 after investigation of lots of arm* funcs, now using more optimized metho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
    [BaseDefs.hpp, SynthSettings.hpp]
2021-08-08 #96 using optimized block ops in filter (saves ~2% CPU) #116 completing k-rate mod support. polyBlepOscillator no longer supports A-Rate freq & amp mod polyBlepOscillator now ignores processing when 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
    [SynthSettings.hpp]
2021-08-21 - upgrading to teensyduino 1.54 - adding support for the new crashandler - optimizing some mem usage after profiling with bloaty
    [BassoonoidMain.cpp, SynthSettings.hpp]
2021-09-04 resetting pb up default
    [SynthSettings.hpp]
2021-09-06 #111 changing fingerings a bit to facilitate some trills fixing a typo regarding sync enabled
2021-09-11 #121: key state is now directly in sync with hardware, preventing desync, and allowing reliable startup while keys are touched. #123: sync / main phase accumulators are now controlled properly to swa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
    [ControlMapping.hpp, SynthSettings.hpp]
2021-11-11 fixes #127 adding octave LED indicator fixes #126 adding a breath min setting to Gui Performance page, AND now with fine control.
    [UnipolarCalibration.hpp]
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2022-05-27 corrections to synth patches for au bassin show increase min pressure to avoid ghost notes which happened at BBP i recall adding software for the midi note inserter thing adding kicad project for mid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
    [midiperformer-B_Cu.gbl, midiperformer-B_Mask.gbs, midiperformer-B_Paste.gbp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]
2022-06-02 progress on midiperformer; this one is being printed progress on clarinoid3 schematic; very WIP
    [clarinoid3.kicad_pcb, clarinoid3.sch, midiperformer.kicad_pcb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]
2022-06-10 adding a bunch of kicad progress mostly on test device, lots of footprints & symbols
    [CapSliderPatternTester.kicad_pcb, CapSliderPatternTester.kicad_sch, clarinoid-devboard.kicad_pcb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]
2022-06-14 incremental progress of clarinoid test device renaming midi performer to prepare for rev2
    [clarinoid-devboard.csv, clarinoid-devboard.kicad_pcb, clarinoid-devboard.kicad_sch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]
2022-06-14 midi performer REV2 ordered from jlcpcb
    [BOM.csv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]
2022-06-20 a bunch of PCB work. devboard-04 now in production.
    [35RAPC4BV4.step, BOM-clarinoid-devboard.csv, DAC.kicad_sch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]
2022-06-20 revision needed to production file: audio jack pin footprint was wrong orientation.
    [BOM-clarinoid-devboard.csv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]
2022-06-26 adding a hardware layout sketch to the midi performer device PCB progress on the clarinoid3 body
    [DAC.kicad_sch, LHBoard.kicad_sch, LHCaptouch.kicad_sch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]
2022-06-26 adding midi performer rev 3 PCB design
    [BOM-midiperformer.csv, BOM.csv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]
2022-06-28 created clarinoid presets for Cave Bouncer more clarinoid3 pcb WIP midi performer application WIP; transitioning to Teensy4
    [DAC.kicad_sch, LHBoard.kicad_sch, LHCaptouch.kicad_sch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]
2022-06-30 FM now works pretty reliably #130 sine wave was getting into broken state because mT was > 1. #131 oscillator gain is now applied in the multimixer, allowing FM from silent oscillators. Menu added fo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
    [SynthSettings.hpp]
2022-06-30 removing pitchbend snap; it's not useful adding mod curves to synth settings menu adding freq mul & freq offset to modulation destinations modulations affecting FM strength now work when base value !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
    [SynthSettings.hpp]
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2022-07-02 fixes #132 #133: phase modulation is no longer accumulated with phase accumulator; more predictable and musical results, plays better with multiple modulations, and matches better DX sound
    [SynthSettings.hpp]
2022-07-08 pcb incremental
    [BOM-clarinoid-bodytest.csv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]
2022-07-15 clarinoid test device 5 work; schematic, routing & layout should be done. BOM, panelization, and outlines to do
    [clarinoid-devboard.csv, clarinoid-devboard.kicad_pcb, clarinoid-devboard.kicad_sch]
2022-07-15 incremental WIP on clarinoid3 body design
    [BOM-clarinoid-bodytest.csv, DAC.kicad_sch, LHBoard.kicad_sch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]
2022-07-17 devboard rev 2 i think is ready for assembly
    [BOM-clarinoid-devboard.csv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]
2022-08-28 adding changes leftover from MSI crash. basically a working & tested devboard 5 (same as 6). for some reason, newlines changed.
    [BOM-clarinoid-devboard.csv, Clarinoid3_Breath.sch, Clarinoid3_LH.sch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]
2022-09-11 adding devboard 07 sent to jlcpcb - battery charge circuits removing garbage devboard files
    [BOM-clarinoid-devboard.csv, bom.csv, captouch_capsense.kicad_sch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]
2022-09-14 bommanoid design work
    [BOM-clarinoid-devboard.csv, FinalBaseMesh.obj, bommanoid00.kicad_pcb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]
2022-09-19 bomma design progress
    [bell.kicad_sch, bommanoid00.kicad_pcb, bommanoid_batt_bottom.kicad_sch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]
2022-09-25 progress on bommanoid pcb design adding some winisd simulations
    [BOM-clarinoid-devboard.csv, bell.kicad_sch, bommanoid_batt_bottom.kicad_sch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]
2022-09-25 bommanoid1 pcb design more-or-less complete; need panelization & BOM to fab
    [PH_breakout.kicad_sch, bell.kicad_sch, bommanoid_batt_bottom.kicad_sch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]
2022-09-28 bommanoid05 sent to production
    [PH_breakout.kicad_sch, bell.kicad_sch, bom.csv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]
2022-10-02 - bommanoid project forked from bassoonoid, now builds. does not work or anything yet but next transition to usb host & decouple from breath. - moving some documentation to a better place, added docs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
    [BommanoidMain.cpp]
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2022-10-02 support for pca9554, some fixes and now menu system works. next up: musical state.
    [BommanoidMain.cpp]
2022-10-02 fixing bugs in held key tracker added prelim bommanoid synth patch
    [HarmonizerSettings.hpp, SynthSettings.hpp]
2022-10-04 polyphonic synth work is coming along. voices are distributed smartly but synth graph not working atm.
    [SynthSettings.hpp]
2022-10-05 fixed modulations & envelopes so that polyphony works. still some issues with stuck notes.
    [SynthSettings.hpp]
2022-10-09 adding voice state, work on polyphony, adding rew test results for bommanoid cab breath filter is now in modulations, mimicking massive keytracking some little intermediate bug fixes
    [SynthSettings.hpp]
2022-10-09 the massive-style filter frequency works well enough that i now do it for oscillator frequency. it adds FreqParam and FreqParamKT, which allows sync frequency to be fully configured via modulations.
    many modulation destinations are no longer working though; much of that needs to be refined and re-established.
    [SynthSettings.hpp]
2022-10-10 fixes #148: adding ability to mute oscillators quickly fixes #145: osc submenu caption displays more info
    [SynthSettings.hpp]
2022-10-10 fixes #134 krate modulations now always set each frame, preventing "open drain"
2022-10-10 #149 verb & delay are now "mix" rather than send. #144 oscillator gain is now a "volume" parameter with squared param curve for modulation-friendliness.
    [volumeparams.xlsx]
2022-10-26 #150 krate destinations are now handled in the mod matrix, removing a bunch of dumb junk from the synth voice code adding disabled filter option saving CPU adding dupe event checker as a way to avoid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
    [BommanoidMain.cpp, SynthSettings.hpp]
2022-10-26 bommanoid enclosure sketches
    [enclosurefinal00.kicad_pcb]
2022-10-28 adding default polarity treatment (#161) fixed volume param clamping below 0 (#161) removing unused (+confusing) polarity and range values for mod destinations introducing a fixed point class which i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
    [SynthSettings.hpp]
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2022-10-30 small fixes and more cleanup in synth
    [SynthSettings.hpp]
2022-10-30 fixes #162; aux now is an attenuation from the main modulation
    [SynthSettings.hpp]
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2022-10-31 sync square is now its own waveform and further waveform types will be their own issues; this closes #110
    [SynthSettings.hpp]
2022-10-31 fixes #138: adding lfo3 and env3
    [SynthSettings.hpp]
2022-11-01 Major synth refactoring to make way for harmonizer, loopstation, and clarinoid device (#168, #167) separating out a bunch of ideas that used to be mashed together: - musical physical device which rec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
    [SynthSettings.hpp, USBKeyboardMusicalDevice.hpp]
2022-11-01 intermediate tweaks, fixes, refinements in pursuit of harmonizer reintroduction #168 musical devices now handle their own musical voice conversion support for emitting synth patch b harmonizer menu r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
    [HarmonizerSettings.hpp]
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2022-11-03 tiny menu tweaks, cleanups toast display shorter
    [SynthSettings.hpp]
2022-11-09 much work done in pursuit of #166 adding json serialization support for many parameters adding structure to some settings, minor cleanups here and there fixing issue where pedal was sometimes not ini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
    [BaseDefs.hpp, ControlMapper.hpp, ControlMapping.hpp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]
2022-11-10 memory shuffling and optimizations which haven't been done in a while. running short and appsettings is a big culprit. putting modcurve lut data out of DMAMEM, to save 32kb. performance barely affect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
    [BommanoidMain.cpp, HarmonizerSettings.hpp]
2022-11-11 adding basis for modal dialog stack, though because of input problems it's half-baked adding loading & saving to USB mass storage device adding Result type
    [BaseDefs.hpp, SynthParamValues.hpp]
2022-11-12 synth settings serialization code in place, but not working.
    [ControlMapper.hpp, SynthParamValues.hpp, SynthSettings.hpp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]
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2022-11-15 for fun, adding #187 ring modulation support also 1 step closer to #182 tighter oscillator feedback processing
    [SynthParamValues.hpp, SynthSettings.hpp]
2022-11-16 most tests are very obsolete; sweeping them under the rug test project now builds again, with serialization support fixing some json formatting & support for empty arrays & objects adding harmonizer 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
    [ControlMapping.hpp, HarmonizerSettings.hpp, SynthParamValues.hpp]
2022-11-19 huge commit related to #166, testing also adding enable/disable to modulations size-optimized serialization code itself, mostly unfolding templates size-optimization: some enum code, CCASSERT string 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
    [BaseDefs.hpp, ControlMapping.hpp, HarmonizerSettings.hpp]
2022-11-20 FM processing improvements: - #182, processing entirely in the oscillator class. - processing in 32-bit only - processing per sample instead of per buffer - osc display name is better for fm sources
    [SynthSettings.hpp]
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2022-11-20 #179 delay send is fixed: typos + frequency parameter was all messed up (KT and param both) removed DC filter which is not useful at voice level
    [SynthSettings.hpp]
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2022-11-22 #193 adding docs, tests, other code to help analysis. refining fm param ranges
    [osc accuracy analysis x86 comparison.xlsx]
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2022-11-23 abstracting sample processing to help get towards multi-oscillator
2022-11-29 FP oscillators. now using structured OscWaveformShape enum instead of the teensy audio constants removing ringmod because it's simple, but hard to make musical. it's not a priority, needs rethinking,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
2022-12-29 sketching out oscillator gen code in reascript, explorations...
    [main.cpp]
2023-01-04 adding some profiling code, support for fixed point lib
    [tehnumbers.xlsx]
2023-01-08 adding massively improved fixed point class with type fluidity and basic arith working. adding assets for benchmarking, more tests
    [tehnumbers.xlsx]
2023-01-11 more arithmetic stuff, the fixed point class is now pretty complete. need to write unit tests.
    [div64.ino]

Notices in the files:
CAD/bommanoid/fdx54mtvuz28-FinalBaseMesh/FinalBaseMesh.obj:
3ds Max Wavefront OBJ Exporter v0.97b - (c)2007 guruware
